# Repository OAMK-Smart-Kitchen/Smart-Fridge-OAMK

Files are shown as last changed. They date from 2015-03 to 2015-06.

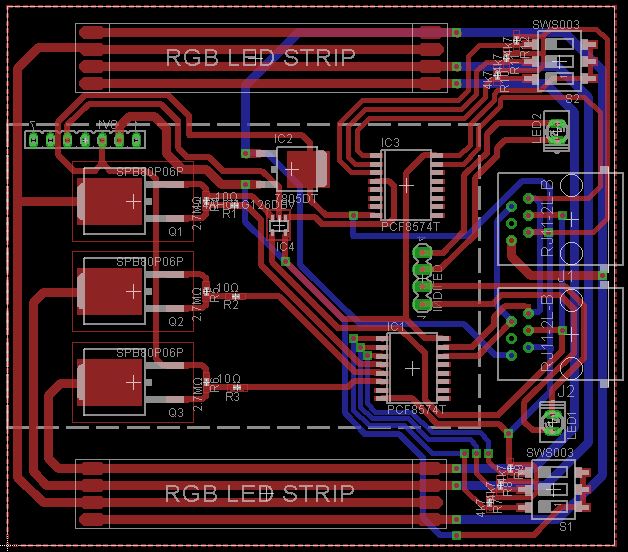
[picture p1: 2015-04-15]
SmartKitchen-Emdebbed System/Hardware/PCB-designs/BRD 2 .JPG

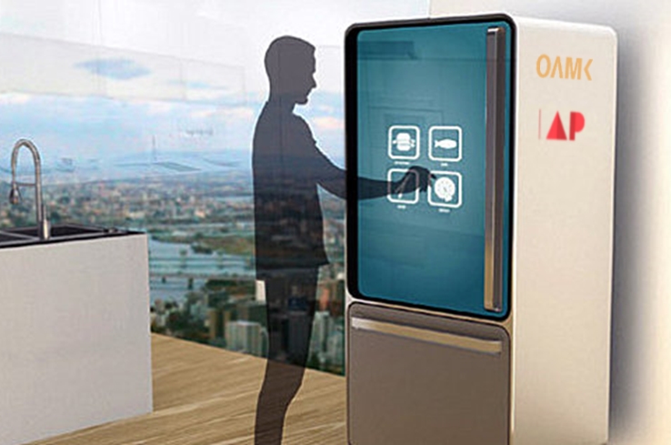
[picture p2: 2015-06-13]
SmartKitchen-Emdebbed System/Documents/Report/Contents/front.jpg

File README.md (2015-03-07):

# Smart-Fridge-OAMK
The first project of the 'Smart Kitchen' commissioned by OAMK University of Applied Sciences in Oulu - Finland.

The concept: [Prezi](http://prezi.com/kkwk0fvxtakd/?utm_campaign=share&utm_medium=copy&rc=ex0share)
The Moqups: [Moqups](https://moqups.com/berndv/YKEUgVQ0)

Dedicated to Tom Mampaey and Bernd Verhofstadt (Erasmus students from Belgium) by:

### Contactpersons Finland:
#### Mr. Jussi Kangasoja
Email: Jussi.Kangasoja@oamk.fi

#### Ms. Kaisa Orajärvi
Email: kaisa.orajarvi@oamk.fi

### Contactperson Belgium:
#### Mr. Jeroen Doggen
Email: jeroen.doggen@ap.be

Github: [github.com/jeroendoggen](https://github.com/jeroendoggen)

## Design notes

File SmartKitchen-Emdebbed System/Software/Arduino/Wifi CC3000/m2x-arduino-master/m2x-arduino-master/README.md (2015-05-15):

Arduino M2X API Client
=====================

The Arduino library is used to send/receive data to/from [AT&amp;T's M2X service](https://m2x.att.com/) from [Arduino](http://www.arduino.cc/) based devices.

**NOTE**: Unless stated otherwise, the following instructions are specific to [Arduino Uno](http://arduino.cc/en/Main/arduinoBoardUno) board. If you are using other boards, the exact steps may vary.

Getting Started
==========================
1. Signup for an [M2X Account](https://m2x.att.com/signup).
2. Obtain your _Master Key_ from the Master Keys tab of your [Account Settings](https://m2x.att.com/account) screen.
3. Create your first [Data Source Blueprint](https://m2x.att.com/blueprints) and copy its _Feed ID_.
4. Review the [M2X API Documentation](https://m2x.att.com/developer/documentation/overview).
5. Obtain an Arduino with built in wifi or ethernet, or a separate wifi or ethernet shield and [set it up](http://arduino.cc/en/Guide/HomePage). These docs were written for an [__Arduino Uno__](http://arduino.cc/en/Main/arduinoBoardUno) with a wifi or ethernet shield but the instructions can be adapted for other Arduino models.

Please consult the [M2X glossary](https://m2x.att.com/developer/documentation/glossary) if you have questions about any M2X specific terms.

How to Install the library
==========================

This library depends on [jsonlite](https://github.com/citrusbyte/jsonlite), the installation steps are as follows:

1. Clone the [jsonlite](https://github.com/citrusbyte/jsonlite) repository.

   **NOTE**: Since we are now using the old v1.1.2 API(we will migrate to the new API soon), please use the fork version of jsonlite listed above instead of the original one.

2. Open the Arduino IDE, click `Sketch->Import Library...->Add Library...`, then navigate to `amalgamated/jsonlite` folder in the cloned jsonlite repository. The jsonlite library will be imported to Arduino this way.

   **NOTE**: If you cloned the jsonlite library, there will be 3 folders named jsonlite:
   * `jsonlite`: the repo folder
   * `jsonlite/jsonlite`: the un-flattened jsonlite source folder
   * `jsonlite/amalgamated/jsonlite`: the flattened jsonlite source for arduino

   The last one here should be the one to use, the first 2 won't work!
3. Use the instructions outlined in Step 2 above to import the `M2XStreamClient` library in the current folder.
4. Now you can find M2X examples under `File->Examples->M2XStreamClient`
5. Enjoy coding!

Hardware Setup
==============

Board Setup
-----------

The Arduino website has a very good [tutorial](http://arduino.cc/en/Guide/HomePage) on setting up the Arduino board. It contains detailed instructions on how to install the Arduino IDE, sets up your board for initial testing. Feel free to proceed to the [Arduino site](http://arduino.cc/en/Guide/HomePage) to get a basic idea on Arduino.

Wifi/Ethernet Shield Setup
--------------------------

If you are using an [Arduino Yun](http://arduino.cc/en/Main/ArduinoBoardYun) board instead of an [Arduino Uno](http://arduino.cc/en/Main/ArduinoBoardUno) board, you can skip this section since the Yun board already has Wifi adapter on board.

To send data to the AT&amp;T M2X service, or receive data from the AT&amp;T M2X service, your Arduino board needs a connection to the Internet. Hence an Arduino [Wifi Shield](http://arduino.cc/en/Main/ArduinoWiFiShield) or [Ethernet Shield](http://arduino.cc/en/Main/ArduinoEthernetShield) is needed to give your board the power to connect to the Internet. To install the shield, hook the shield on your Arduino board — you can use the pins on the shield the same way as the real pins on the Arduino boards.

Sensor Setup
------------

Different sensors can be hooked up to an Arduino board to provide different properties including temperatures, humidity, etc. You can use a breadboard as well as wires to connect different sensors to your Arduino. For detailed tutorial on connecting different sensors, please refer to the Arduino [Examples page](http://arduino.cc/en/Tutorial/HomePage).

3G Shield Setup
------------

If you are using a 3G GSM/GPRS shield with your Arduino, the [M2X Arduino SIMCOM module](https://github.com/attm2x/m2x-arduino-simcom) can be used to connect your device to the AT&T cellular data network.

Variables used in Examples
==========================

In order to run the given examples, different variables need to be configured. We will walk through those variables in this section.

Network Configuration
---------------------

If you are using a Wifi Shield, the following variables need configuration:

```
char ssid[] = "<ssid>";
char pass[] = "<WPA password>";
```

Just fill in the SSID and password of the Wifi hotspot, you should be good to go.

For an Ethernet Shield, the following variables are needed:

```
byte mac[] = { 0xDE, 0xAD, 0xBE, 0xEF, 0xFE, 0xED };
IPAddress ip(192,168,1,17);
```

For a newer Ethernet Shield, the MAC address should be printed on a sticker on the shield. However, some sold Ethernet Shields have no MAC address shown on the board. In this case, you can use any MAC address, as long as it is not conflicted with another network device within the same LAN.

The IP address here is only used when DHCP fails to give a valid IP address. It is recommended, though not required, to provide a unique IP address here.

M2X API Key
-----------

Once you [register](https://m2x.att.com/signup) for an AT&amp;T M2X account, an API key is automatically generated for you. This key is called a _Primary Master Key_ and can be found in the _Master Keys_ tab of your [Account Settings](https://m2x.att.com/account). This key cannot be edited nor deleted, but it can be regenerated. It will give you full access to all APIs.

However, you can also create a _Data Source API Key_ associated with a given Data Source(Feed), you can use the Data Source API key to access the streams belonging to that Data Source.

You can customize this variable in the following line in the examples:

```
char m2xKey[] = "<M2X access key>";
```

Feed ID
-------

A feed is associated with a data source, it is a set of data streams, such as streams of locations, temperatures, etc. The following line is needed to configure the feed used:

```
char feedId[] = "<feed id>";
```

Stream Name
------------

A stream in a feed is a set of timed series data of a specific type(i,e. humidity, temperature), you can use the M2XStreamClient library to send stream values to M2X server, or receive stream values from M2X server. Use the following line to configure the stream if needed:

```
char streamName[] = "<stream name>";
```

Using the M2XStreamClient library
=========================

The M2X Arduino library can be used with both Wifi connection and Ethernet connection. For a Wifi connection, use the following code:

```
WiFiClient client;
M2XStreamClient m2xClient(&client, m2xKey);
```

For an Ethernet connection, use the following code:

```
EthernetClient client;
M2XStreamClient m2xClient(&client, m2xKey);
```

If you are using an [Arduino Yun](http://arduino.cc/en/Main/ArduinoBoardYun) board specifically, you should use the following code:

```
YunClient client;
M2XStreamClient m2xClient(&client, m2xKey);
```

In the M2XStreamClient, 4 types of API functions are provided here:

* `send`: Send stream value to M2X server
* `receive`: Receive stream value from M2X server
* `updateLocation`: Send location value of a feed to M2X server
* `readLocation`: Receive location values of a feed from M2X server

Returned values
---------------

For all those functions, the HTTP status code will be returned if we can fulfill a HTTP request. For example, `200` will be returned upon success, `401` will be returned if we didn't provide a valid M2X API Key.

Otherwise, the following error codes will be used:

```
static const int E_NOCONNECTION = -1;
static const int E_DISCONNECTED = -2;
static const int E_NOTREACHABLE = -3;
static const int E_INVALID = -4;
static const int E_JSON_INVALID = -5;
```

Post stream value
-----------------

The following functions can be used to post value to a stream, which belongs to a feed:

```
template <class T>
int post(const char* feedId, const char* streamName, T value);
```

Here we use C++ templates to generate functions for different types of values, feel free to use values of `float`, `int`, `long` or even `const char*` types here.

Post multiple values
--------------------

M2X also supports posting multiple values to multiple streams in one call, use the following function for this:

```
template <class T>
int postMultiple(const char* feedId, int streamNum,
                 const char* names[], const int counts[],
                 const char* ats[], T values[]);
```

Please refer to the comments in the source code on how to use this function, basically, you need to provide the list of streams you want to post to, and values for each stream.

Fetch stream value
------------------

Since Arduino board contains very limited memory, we cannot put the whole returned string in memory, parse it into JSON representations and read what we want. Instead, we use a callback-based mechanism here. We parse the returned JSON string piece by piece, whenever we got a new stream value point, we will call the following callback functions:

```
void (*stream_value_read_callback)(const char* at,
                                   const char* value,
                                   int index,
                                   void* context);

```

The implementation of the callback function is left for the user to fill in, you can read the value of the point in the `value` argument, and the timestamp of the point in the `at` argument. We even pass the index of this this data point in the whole stream as well as a user-specified context variable to this function, so as you can perform different tasks on this.

To read the stream values, all you need to do is calling this function:

```
int fetchValues(const char* feedId, const char* streamName,
                stream_value_read_callback callback, void* context,
                const char* startTime = NULL, const char* endTime = NULL,
                const char* limit = NULL);
```

Besides the feed ID and stream name, only the callback function and a user context needs to be specified. Optional filtering parameters such as start time, end time and limits per call can also be used here.

Update Datasource Location
--------------------------

You can use the following function to update the location for a data source(feed):

```
template <class T>
int updateLocation(const char* feedId, const char* name,
                   T latitude, T longitude, T elevation);
```

Different from stream values, locations are attached to feeds rather than streams.

The reasons we are providing templated function is due to floating point value precision: on most Arduino boards, `double` is the same as `float`, i.e., 32-bit (4-byte) single precision floating number. That means only 7 digits in the number is reliable. When we are using `double` here to represent latitude/longitude, it means only 5 digits after the floating point is accurate, which means we can represent as accurate to ~1.1132m distance using `double` here. If you want to represent cordinates that are more specific, you need to use strings here.

Read Datasource Location
------------------------

Similar to reading stream values, we also use callback functions here. The only difference is that different parameters are used in the function:

```
void (*location_read_callback)(const char* name,
                               double latitude,
                               double longitude,
                               double elevation,
                               const char* timestamp,
                               int index,
                               void* context);

```

For memory space consideration, now we only provide double-precision when reading locations. An index of the location points is also provided here together with a user-specified context.

The API is also slightly different, in that the stream name is not needed here:

```
int readLocation(const char* feedId, location_read_callback callback,
                 void* context);

```

Delete Values
-------------

You can use the following function to delete values within a stream by providing a `from` and `end` date/time:

```
int deleteValues(const char* feedId, const char* streamName, 
                 const char* from, const char* end);
```

The timestamps `from` and `end` need to be in an ISO 8601 format: yyyy-mm-ddTHH:MM:SS.SSSZ. Note the Z for Zulu time.

Examples
========

We provide a series of examples that will help you get an idea of how to use the `M2XStreamClient` library to perform all kinds of tasks.

Note that the examples may apply to certain types of boards. For example, the ones with `Uno` in the name apply to `Arduino Uno` boards, while the ones with `Yun` apply to `Arduino Yun` boards.

Note that the examples contain fictionary variables, and that they need to be configured as per the instructions above before running on your Arduino board. Each of the examples here also needs either a Wifi Shield or an Ethernet Shield hooked up to your device.

In the `UnoPost`, `EthernetUnoPost` and `YunPost`, a temperature sensor, a breadboard and 5 wires are also needed to get temperature data, you need to wire the board like [this](http://cl.ly/image/3M0P3T1A0G0l) before running the code.

After you have configured your variables and the board, plug the Arduino board into your computer via a Micro-USB cable, click `Verify` in the Arduino IDE, then click `Upload`, and the code should be uploaded to the board. You can check all the outputs in the `Serial Monitor` of the Arduino IDE.

UnoPost
-------

This example shows how to post temperatures to M2X server. Before running this, you need to have a valid M2X Key, a feed ID and a stream name. The Arduino board needs to be configured like [this](http://cl.ly/image/3M0P3T1A0G0l). In this example, we are using an [Arduino Uno](http://arduino.cc/en/Main/arduinoBoardUno) board. If you are using other boards, keep in mind that we are reading from `A0` in the code, the wiring should be similar to this one shown in the illustration.

UnoPostMultiple
---------------

This example shows how to post multiple values to multiple streams in one API call.

UnoFetchValues
--------------

This example reads stream values from M2X server. And prints the stream data point got to Serial interface. You can find the actual values in the Arduino `Serial Monitor`.

EthernetUnoPost
---------------

This one is similar to the `UnoPost`, except that EthernetClient is used instead of WifiClient. If you are using an Ethernet Shield instead of a Wifi Shield, you can use this example.

EthernetUnoReceive
------------------

This one is similar to the `UnoReceive`, except that EthernetClient is used instead of WifiClient.

UnoUpdateLocation
-----------------

This one sends location data to M2X server. Idealy a GPS device should be used here to read the cordinates, but for simplicity, we just use pre-set values here to show how to use the API.

UnoReadLocation
---------------

This one reads location data of a feed from M2X server, and prints them to Serial interfact. You can check the output in the `Serial Monitor` of the Arduino IDE.

UnoDelete
---------

This example shows how to delete values within a stream by providing a date/time range.

YunPost
-------

This example works like `YunPost`, except that it works on an [Arduino Yun](http://arduino.cc/en/Main/ArduinoBoardYun) board instead of an [Arduino Uno](http://arduino.cc/en/Main/arduinoBoardUno) board.

LICENSE
=======

This library is released under the MIT license. See [`M2XStreamClient/LICENSE`](M2XStreamClient/LICENSE) for the terms.

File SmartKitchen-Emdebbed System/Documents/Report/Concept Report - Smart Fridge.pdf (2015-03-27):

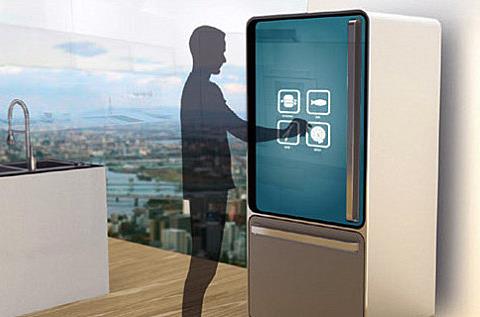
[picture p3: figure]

# Smart Refrigerator

# The first device of the smart kitchen - Seesam

### Tom Mampaey & Bernd Verhofstadt

### Bachelor Electronics – ICT Erasmusstudents: Belgium OAMK - University of Applied Sciences Jan – May 2015

## Table of contents:

## 1. Introduction:

We are both third-year students from ‘Artesis Plantijn Antwerp’ in Belgium. When we saw the opportunity to go on Erasmus to Oulu in Finland and do our Bachelor-project there we did everything to make it possible.
Here we are, and we are very thrilled about the project we got!

## 2. The project:

The project we are doing is a daughter-project of a bigger project of two years to put some intelligence into the ordinary kitchen (Seesam). We have the privilege to be the first two students to contribute to this project.

As stated in the title, we will delve us into the smart refrigerator!
The main idea is to make a refrigerator that will know who’s using it, what he may and what he may not eat and what’s in the refrigerator. The refrigerator will know this based on the current properties of the user (scale for weight, input, BMI-calculator,…).

## 3. Github:

To maintain the structure, workflow and to easily monitor the project we have made a repository on Github for this project. Our request to make it private should be accepted soon. You can find the repository on:
https://github.com/TomMampaey/Smart-Fridge.git

Note: If you have a git-account we can add you to the view-members.

## 4. The idea’s and brainstorm:

- User recognition:
- Fingerprint reader in handheld:
PRO | CONTRA
Very unique (for each person) | You have to touch something
Reliability | Difficult with wet fingers
| Waiting-time
- Active RFID key-hanger or card:
PRO | CONTRA
Detection on distance | Physical object
Multiple use and handy | Can mix up multiple users
Cheap
- Kinect face-recognition:
PRO | CONTRA
Challenging | Delay(?)
Automatic recognition | Height of camera
International team-work | Complex
- Face-recognition Raspberry-Pi:
PRO | CONTRA
Automatic recognition | Delay(?)
Cheap | Height of camera
| Reliability
- Voice-recognition:
PRO | CONTRA
Accessibility | Complex
Cheap | Reliability
Fun
- Motion-detection:
PRO | CONTRA
Energy-saving (only on when motion) | No direct user-recognition
Cheap | Reliability
Easy

- Product recognition and recommendation:
- Barcode-reader:
PRO | CONTRA
Existing databases | Finding a fast way to scan it
| By hand
| Takes time
- NFC-tag:
PRO | CONTRA
Wireless | Attach on the products/tray
Stickers are cheap | Reader on every place
Place-independent
- Mechanical detection/hatches:
PRO | CONTRA
Overview and organization | Moving parts
Reliability | Expensive
Not possible to take other product
- LED’s/ LED-strip
PRO | CONTRA
Clearly what product it is | User can take other products.
Colors for good and bad
Fancy

- Health-detection:
- Integrated scale:
PRO | CONTRA
User-assuredness | Big surface-area
Possibility to calculate BMI | View
No extra action required (for user)
- Personal point-system (based on earlier snacks):
PRO | CONTRA
Motivating for users | Requires many properties of user
Competitive
Possibility to turn off feature
- BMI-calculator:
PRO | CONTRA
Easy calculation | Requires (many) properties of user
User can compare to average | Frustrating
Possibility to turn off feature
- Communication/Platform:
- Raspberry Pi:
PRO | CONTRA
Performance | Limited hardware ports
All-in one computer
Internet-connection
- Arduino:
PRO | CONTRA
Perfect test-device | No internet-connection
Many possibilities | Limited hardware-set
Cheap
- Wi-Fi and Ethernet (LAN):
PRO | CONTRA
Connected devices | Security
Software updates
Monitoring
- Bluetooth:
PRO | CONTRA
Peer-to-peer | Not always reliable
Not connected to the internet | Possible delays
| Can only connect 2 devices at once

Subject | Week 1 | Week 2 | Week 3 | Week 4 | Week 5 | Week 6 | Week 7 | Week 8 | Week 9 | Week 10
Documentation:
Concept-report
Gantt-chart/Project-planning
Brainstroming
Comparing possibilities
Hardware:
Research (target)
Experimenting
Features
Collectting components
Powersupply
Communication
Arduino
Raspberry Pi
User-recognition
Testing
Schematic-design
PCB-desgin
PCB-manufacture
Prototyping
Error analyzes
Software:
Research
Choosing Language(s)
User-recognition
Raspberry Pi
Features
Server-side
GUI
Final:
Final integrating Software - Hardware Finishing hardware
Final Report
Finnishing touth Final Report

## 5. Estimated Gantt-chart:

Subject | Week 11 | Week 12 | Week 13 | Week 14 | Week 15 | Week 16 | Week 17 | Week 18 | Week 19 | Week 20
Documentation:
Brainstroming
Concept-report
Gantt-chart/Project-planning Comparing possibilities
Hardware:
Research (target)
Experimenting
Features
Collectting components
Powersupply
Communication
Arduino
Raspberry Pi
User-recognition
Testing
Schematic-design
PCB-desgin
PCB-manufacture
Prototyping
Error analyzes
Software:
Research
Choosing Language(s)
User-recognition
Raspberry Pi
Features
Server-side
GUI
Final:
Final integrating Software - Hardware Finishing toutch hardware
Final Report
Finnishing Final Report

## The Annex:

Content:

Will be added soon.

Images:

- Front-page image:
http://www.revistaexclusiva.com/?p=25851

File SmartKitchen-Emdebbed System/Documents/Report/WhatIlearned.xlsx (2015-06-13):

Subject | Beginner | Experienced | Advanced | Expert
SMD - design multiple layers
Component desing
Prototyping
SMD component techniques
Arduino/coding
Reasearch/Datasheets
Github
PCB design and placements
Sensors
Schematics
Microscope comp. Placing
Shield construction
Measurement/test equipment
Hardware/Software debug!
I2C protocol
Near Field Communication
WiFi, HTTP methods, ...
PCB manufacturing
Handeling unexpected failures
ASUS Xtion PRO
Raspberry Pi
3D-printing
M2X Development
iPi Mocap Studio
RF-ID
Microsoft Kinect
Wheatstone bridge weightscale
Working independently
Planning skills
Cooperate in English
Tutorial
Time management
Teamwork
Scrum
Preparing meetings
Note: geldt enkel voor dit project, en enkel wat ik heb bijgeleerd!!

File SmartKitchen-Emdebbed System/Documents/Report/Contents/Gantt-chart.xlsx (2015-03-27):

Subject | Week 1 | Week 2 | Week 3 | Week 4 | Week 5 | Week 6 | Week 7 | Week 8 | Week 9 | Week 10 | Subject | Week 11 | Week 12 | Week 13 | Week 14 | Week 15 | Week 16 | Week 17 | Week 18 | Week 19 | Week 20
Documentation: |  |  |  |  |  |  |  |  |  |  | Documentation:
Concept-report |  |  |  |  |  |  |  |  |  |  | Brainstroming
Gantt-chart/Project-planning |  |  |  |  |  |  |  |  |  |  | Concept-report
Brainstroming |  |  |  |  |  |  |  |  |  |  | Gantt-chart/Project-planning
Comparing possibilities |  |  |  |  |  |  |  |  |  |  | Comparing possibilities
Hardware: |  |  |  |  |  |  |  |  |  |  | Hardware:
Research (target) |  |  |  |  |  |  |  |  |  |  | Research (target)
Experimenting |  |  |  |  |  |  |  |  |  |  | Experimenting
Features |  |  |  |  |  |  |  |  |  |  | Features
Collectting components |  |  |  |  |  |  |  |  |  |  | Collectting components
Powersupply |  |  |  |  |  |  |  |  |  |  | Powersupply
Communication |  |  |  |  |  |  |  |  |  |  | Communication
Arduino |  |  |  |  |  |  |  |  |  |  | Arduino
Raspberry Pi |  |  |  |  |  |  |  |  |  |  | Raspberry Pi
User-recognition |  |  |  |  |  |  |  |  |  |  | User-recognition
Testing |  |  |  |  |  |  |  |  |  |  | Testing
Schematic-design |  |  |  |  |  |  |  |  |  |  | Schematic-design
PCB-desgin |  |  |  |  |  |  |  |  |  |  | PCB-desgin
PCB-manufacture |  |  |  |  |  |  |  |  |  |  | PCB-manufacture
Prototyping |  |  |  |  |  |  |  |  |  |  | Prototyping
Error analyzes |  |  |  |  |  |  |  |  |  |  | Error analyzes
Software: |  |  |  |  |  |  |  |  |  |  | Software:
Research |  |  |  |  |  |  |  |  |  |  | Research
Choosing Language(s) |  |  |  |  |  |  |  |  |  |  | Choosing Language(s)
User-recognition |  |  |  |  |  |  |  |  |  |  | User-recognition
Raspberry Pi |  |  |  |  |  |  |  |  |  |  | Raspberry Pi
Features |  |  |  |  |  |  |  |  |  |  | Features
Server-side |  |  |  |  |  |  |  |  |  |  | Server-side
GUI |  |  |  |  |  |  |  |  |  |  | GUI
Final: |  |  |  |  |  |  |  |  |  |  | Final:
Final integrating Software - Hardware |  |  |  |  |  |  |  |  |  |  | Final integrating Software - Hardware
Finishing hardware |  |  |  |  |  |  |  |  |  |  | Finishing toutch hardware
Final Report |  |  |  |  |  |  |  |  |  |  | Final Report
Finnishing touth Final Report |  |  |  |  |  |  |  |  |  |  | Finnishing Final Report

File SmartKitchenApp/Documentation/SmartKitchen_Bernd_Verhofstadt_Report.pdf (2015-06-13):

# Project

# Sesam

-‐

# Smart

# Kitchen Smart

# Fridge

Spring

2015

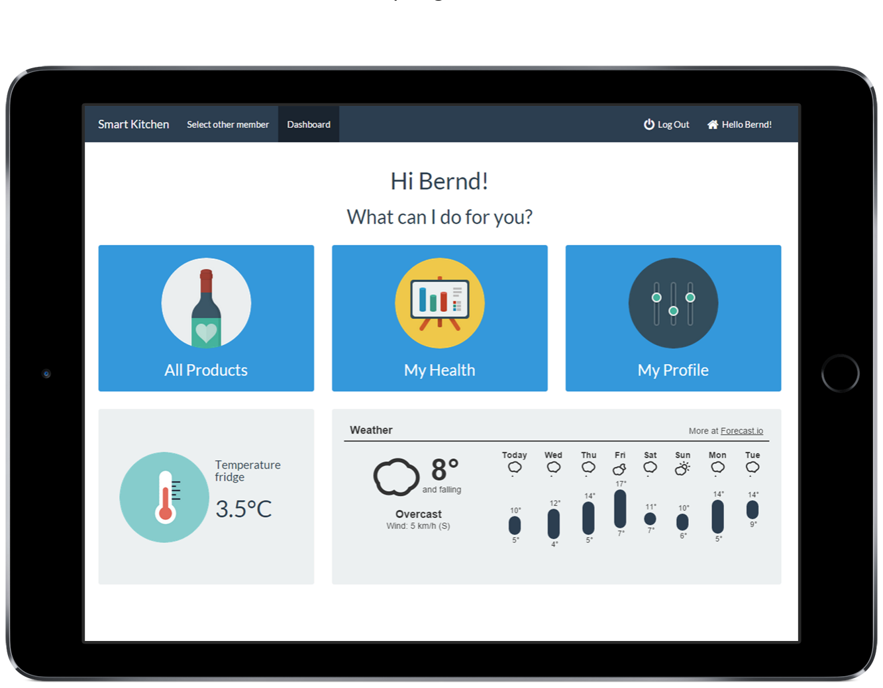
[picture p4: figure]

Student
Bernd

Verhofstadt
Heiligenweg

29
D-‐47626

Kevelaer
bernd.verhofstadt@outlook.com

Sending

institution
Artesis

Plan8jn

University

College
Paardenmarkt

92
2180

Antwerp
Belgium

Receiving

institution
OAMK

-‐

Oulun

seudun

ammaAkorkeakoulu
Kotkantie

1
90250

Oulu
Finland

© 2015 Bernd Verhofstadt | Smart Fridge | Page 2 of 16

## Table

of

## contents

1. Introduction

4
2. Brainstorm

5
3. Research

5
4. Work

Methods

6
User

requirements

6
Scrum

board

6
Weekly

meeting

7
Standup

meeting

7
Sprint

8
Git

8
5. SoVware

structure

8
Front

end

8
Back

end

8
6. Application

9
Frameworks

and

technologies

10
User

interface

10
GitHub

13
Windows

Application

13
7. Web

Api

2

14
Frameworks

and

technologies

15
GitHub

15
Technical

information

with

problems

and

solutions

15
8. Reference

list

16

## 1. Introduction

Technology

is

not

standing

still.

We

want

more

and

more

automated

devices.

These

devices

will

be

used
on

a

daily

basis.

A

house

is

a

place

where

you

can

find

a

lot

of

these

things,

for

example

the

kitchen.

The
Sesam

project

is

based

on

a

voice

character.

When

you

call

Sesam,

he/she

can

do

something

like

“Sesam
open”.

The

Sesam

project

is

a

smart

kitchen

where

you

could

do

the

same.

For

this

project

I

worked

with
Tom

Mampaey

on

the

Smart

Fridge,

a

spin-‐off

from

the

Smart

Kitchen.

In

the

beginning

we

had

only

two
words.

Smart

and

Kitchen.

## 2. Brainstorm

The

first

step

to

the

project

was

our

brainstorming

session.

A

blank

paper

on

the

table

with

only

the
words

‘Smart

Fridge’.

The

ideas

that

where

wriben

on

the

paper

where

very

different.

Some

major

ideas:
-‐

When

standing

before

the

fridge,

you’ll

be
recognized
-‐

Voice

control

like

Siri,

Google

now,

…

-‐>
Text-‐To-‐Speech

and

Speech-‐To-‐Text
-‐

Glass

screen

with

touch

functionality
-‐

See

what

products

are

in

the

fridge
-‐

Get

recipes

suggestions

what’s

in

the
fridge
-‐

Challenge

your

family

with

points

to

eat

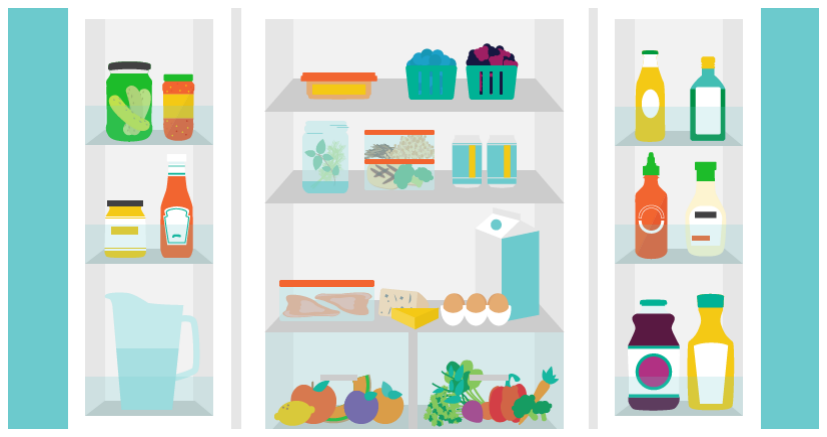
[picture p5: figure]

healthy
-‐

Order

food

online

on

your

fridge
With

these

ideas

we

made

a

selection,

what

looked

possible

in

a

Gme

period

of

four

months.

To

discover
the

possibilities

we

did

some

research

and

tests.

## 3. Research

The

first

thing

that

I

wanted

to

make,

was

a

user

interface.

Easiest

thing

that

I

could

do

was

grab

a
computer,

screen,

keyboard

and

mouse

and

build

it

in

the

fridge.

This

solution

is

not

the

best

one…

It’s
expensive

and

overkill

on

hardware.

So

we

decided

that

we

wouldn’t

use

a

desktop

computer

in

the
fridge.
As

mentioned

above,

a

full

size

computer

isn’t

the

best

option.

But

when

there

are

computers

with
limited

hardware

which

are

less

expensive,

like

Raspberry

Pi

it

could

be

a

great

choice.
I

started

with

doing

tests

on

the

Raspberry

Pi.

Voice

control

was

on

the

list

so

I

did

a

lot

of

research

on
this

subject.

I

found

some

companies

that

offered

‘free’

STT

(Speech

to

Text).

I

looked

into

it

but

the
results

were

not

satisfactory.

Google

chrome

was

a

solution

but

as

it

won’t

work

on

Raspberry

pi,

this
wasn’t

an

option.

Because

of

the

limited

budget

and

Gme

that

we

had

to

spend,

I

decided

not

to

use

STT.
I

was

testing

with

Raspberry

Pi

to

make

a

user

interface

but

it

was

not

user

friendly,

you

only

can

use
limited

graphics

due

to

the

limited

hardware.
I

needed

another

solution,

something

more

flexible

to

run.

Everyone

is

using

a

smartphone

or

tablet
these

days,

thus

I

was

thinking

about

a

mobile

application.

But

the

question

was

for

which

OS.

Because
we

didn’t

have

enough

Gme,

we

had

to

make

a

discussion.

I

was

thinking

about

a

responsive

web
application,

in

this

way

you

can

use

it

on

any

device

with

a

modern

browser

and

internet

connection.
The

web

application

should

be

compatible

with

different

devices

and

easy

to

use.

We

decided

that

I
would

make

a

web

app,

which

at

the

end

can

be

converted

to

a

mobile

application

without

a

lot

of
coding.
To

run

a

web

application,

there

are

two

things

that

you

need.

A

web

server

and

data

storage.
The

advantage

of

an

offline

web

application

is

that

you

don’t

need

an

internet

connection.

The

downside
is

that

It’s

more

difficult

to

deploy

and

you

should

make

an

offline

data

storage.

To

make

it

more

dynamical

and

have

more

options,

I

decided

to

make

everything

in

the

cloud.

Luckily

a

web

server
wasn’t

a

problem,

since

I

have

my

personal

one.
For

the

data

storage,

I

had

to

choice

the

most

suitable

technology

for

the

back-‐end.
Next

step

was

to

do

some

tests

with

different

technologies.

In

the

first

place,

I

wanted

to

learn

something

new.

I

wanted

to

use

NodeJS

with

MongoDB.

With

this
technology

I

had

no

experience

or

idea

how

it

works.

I

did

some

small

projects

but

it

seemed

difficult

to
debug

etc.
I

read

an

article

about

MVC

and

Web

API

and

they

said

that

Web

API

2

is

the

future,

but

MVC

will
disappear

in

a

few

years.

So

I

choose

the

best

one,

Web

API

2.

For

the

database,

I

took

MicrosoV

SQL
Server

2014.

To

make

it

more

flexible,

I

will

use

the

MicrosoV

Entity

Framework.

## 4. Work

## Methods

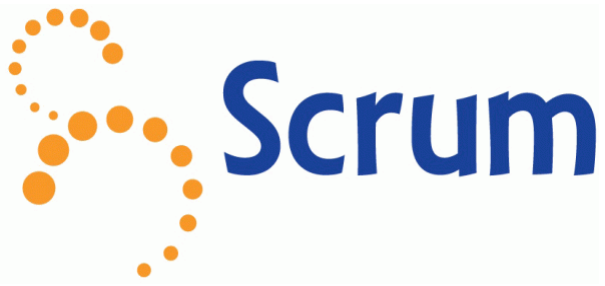
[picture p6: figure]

To

realize

this

project,

we

used

a

few

methods.

The

most
important

one

was

SCRUM.
Scrum

is

a

work

method

that

is

used

for

project
management.

When

using

scrum

there

are

a

lot

of
possibilities,

we

did

a

selection

of

the

most

important
features.

## User

## requirements

I

made

some

user

requirements

for

the

soVware

part.

What

does

the

end

customer

want

?

For

example:
‘As

a

family

member

I

want

to

see

which

products

are

in

the

fridge.

Off

course

we

added

some

priority

to
see

what

we

had

to

do

first.

## Scrum

## board

We

had

a

whiteboard

where

we

made

a

table

with

following

columns:

to

do,

in

progress

and

done.

Framework | Database
.NET MVC | MySQL
Web API 2 | MS SQL
NodeJS | MongoDB

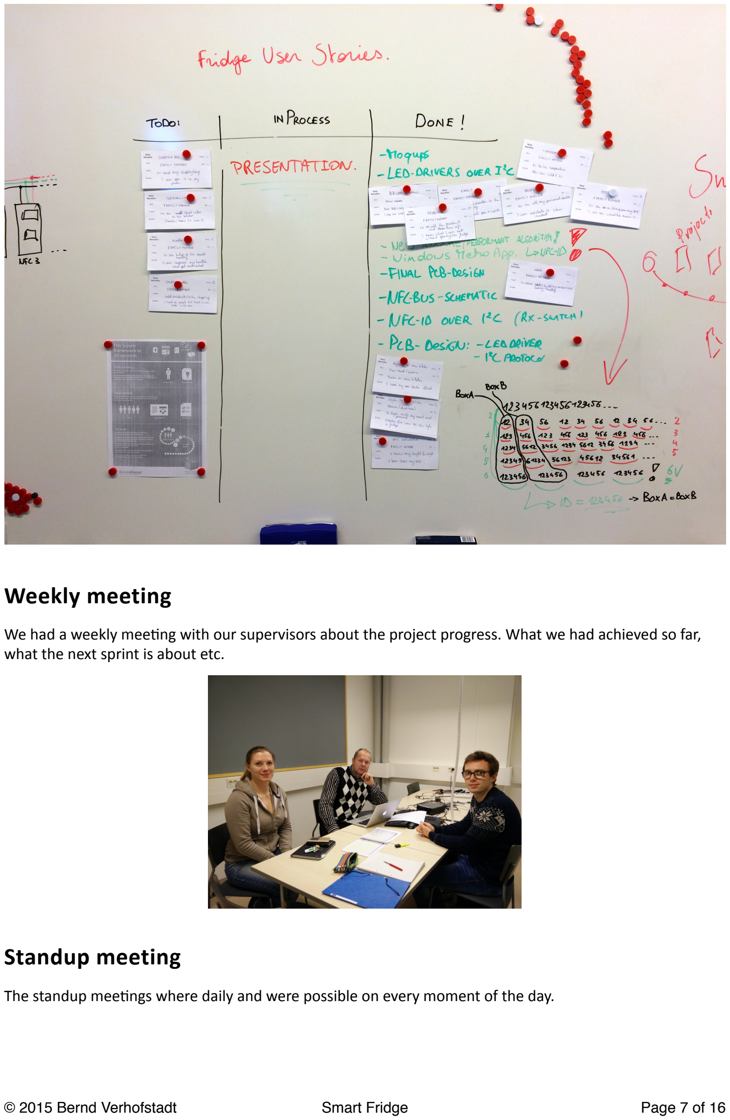
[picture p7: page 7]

## Weekly

## meeting

We

had

a

weekly

meeting

with

our

supervisors

about

the

project

progress.

What

we

had

achieved

so

far,
what

the

next

sprint

is

about

etc.

## Standup

## meeting

The

standup

meetings

where

daily

and

were

possible

on

every

moment

of

the

day.

## Sprint

The

sprint

was

every

two

weeks.

Where

we

had

some

deadlines

that

we

have

to

finish

by

then.

We
discussed

the

sprint

with

the

supervisors.

## Git

We

worked

with

GitHub.

It

is

a

web-‐based

Git

repository

hosting

service,

which

offers

the

full

distributed
revision

control

and

source

code

management

(SCM)

functionality

of

Git

as

well

as

adding

its

own

features.
I

created

an

organization

named

‘OAMK

Smart

Kitchen’

on

GitHub.

All

the

people

that

will

work

on

this
project

can

work

on

there

own

repository

within

the

Smart

Kitchen

organization.
hbps://github.com/OAMK-‐Smart-‐Kitchen (https://github.com/OAMK-Smart-Kitchen)

## 5. Software

## structure

The

soVware

can

be

divided

in

two

parts.

The

back-‐end

and

the

front-‐end.

## Front

## end

The

front

end

is

the

layer

between

the

user

interface

and

the

back

end.

In

the

front

end,

the

client
application

that

is

running,

uses

Angular

/

javascript

to

communicate

with

the

back

end.

The

tablet

is
connected

over

the

home

WiFi

router

with

the

browser

to

the

internet.

## Back

## end

The

back

end

is

the

place

where

the

data

is

stored

on

the

server,

the

point

where

the

user

can

interact

or
request

data

from

the

server.

The

back

end

is

placed

in

a

datacenter.

There

are

several

server

types,

the
Web

server

will

store

the

client

application.

When

the

user

enters

the

URL

from

the

application,

the

web
server

will

send

the

relevant

data

back

to

the

client.
Windows

Server

contains

different

parts,

Sql

Database,

Webtterver

that

runs

Web

API

2

application.

It’s
possible

to

deploy

with

MicrosoV

Deployment

in

Visual

Studio.

The

windows

server

has

a

layer

between

the
Web

API

2

application

and

the

Sql

2014

database,

Entity

Framework.

This

framework

can

generate

a
database

from

a

model,

controller

or

reverse.

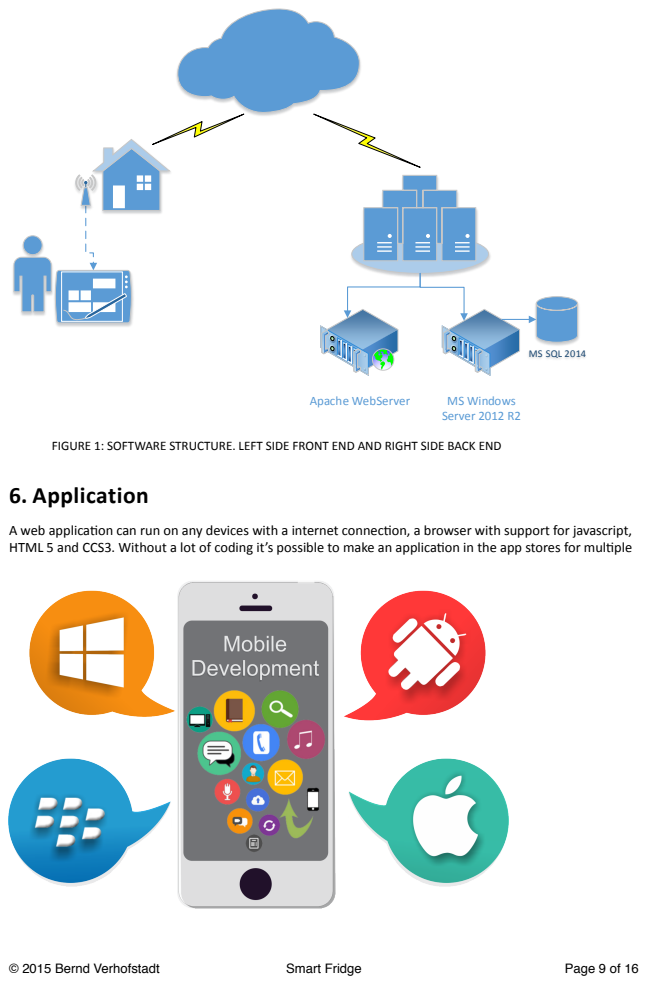
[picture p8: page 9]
FIGURE; SOFTWARE; STRUCTURE.; LEFT; SIDE; FRONT; END; AND; RIGHT; BACK; 6. Application; web; applicaGon; can; run; any; devices; with; internet; connecGon,; browser; support; for; javascript,; HTML; and; CCS3.; Without; lot; coding; possible; make; the; app; stores; mulGple; Apache; WebServer; Windows Server; SQL

OS

with

a

WebView/browser

embedded.

The

web

app

coding

is

for

every

app

the

same,

you

just

have

to
embed

it

in

the

code

of

the

OS.
I

created

a

Windows

App

for

Windows

8

or

higher.

The

Windows

application

contains

a

browser

that

will
load

the

application.

The

advantages

of

a

native

application

is

that

you

have

a

nice

icon

and

don’t

need

any
bookmarks

etc.

The

native

app

will

show

the

web

application

in

full

screen,

in

this

way

the

end

user

will
recognize

it

as

a

real

Mobile

application

and

not

as

an

Website.

## Frameworks

## and

## technologies

- AngularJS
AngularJS

lets

you

write

client-‐side

web

applications

as

if

you

had

a

smarter

browser.

It

lets

you

use

good
old

HTML

as

your

template

language

and

lets

you

extend

HTML’s

syntax

to

express

your

application’s
components

clearly

and

instantly.

It

automatically

synchronizes

data

from

your

UI

(view)

with

your
Javattcript

objects

(model)

through

2-‐way

data

binding.

To

help

you

structure

your

application

beber

and
make

it

easy

to

test,

AngularJS

teaches

the

browser

how

to

do

dependency

injection

and

inversion

of
control.
Oh

yeah

and

it

helps

with

server-‐side

communication,

taming

async

callbacks

with

promises

and
deferreds.

It

also

makes

client-‐side

navigation

and

deep

linking

with

hash-‐bang

URL's

or

HTML5
pushtttate

a

piece

of

cake.

The

best

of

all:

it

makes

development

fun!
- Html
5
HTML

5

is

the

latest

stable

version

of

the

standard.

It

has

a

support

for

geolocation,

we

use

this

for

the
Weather

by

Forecast.io.
- Bootstrap
Bootstrap

is

a

sleek,

intuitive,

and

powerful

front-‐end

framework

for

faster

and

easier

web

development,
created

by

Mark

Obo

and

Jacob

Thornton,

and

maintained

by

the

core

team

with

the

massive

support
and

involvement

of

the

community.

Bootstrap

is

the

most

popular

HTML,

CSS,

and

JS

framework

for
developing

responsive,

mobile

first

projects

on

the

web.

## User

## interface

For

the

user

interface,

I

started

with

a

drawing.

The

drawing

was

a

sketch

with

the

most

important

elements
and

their

shape.

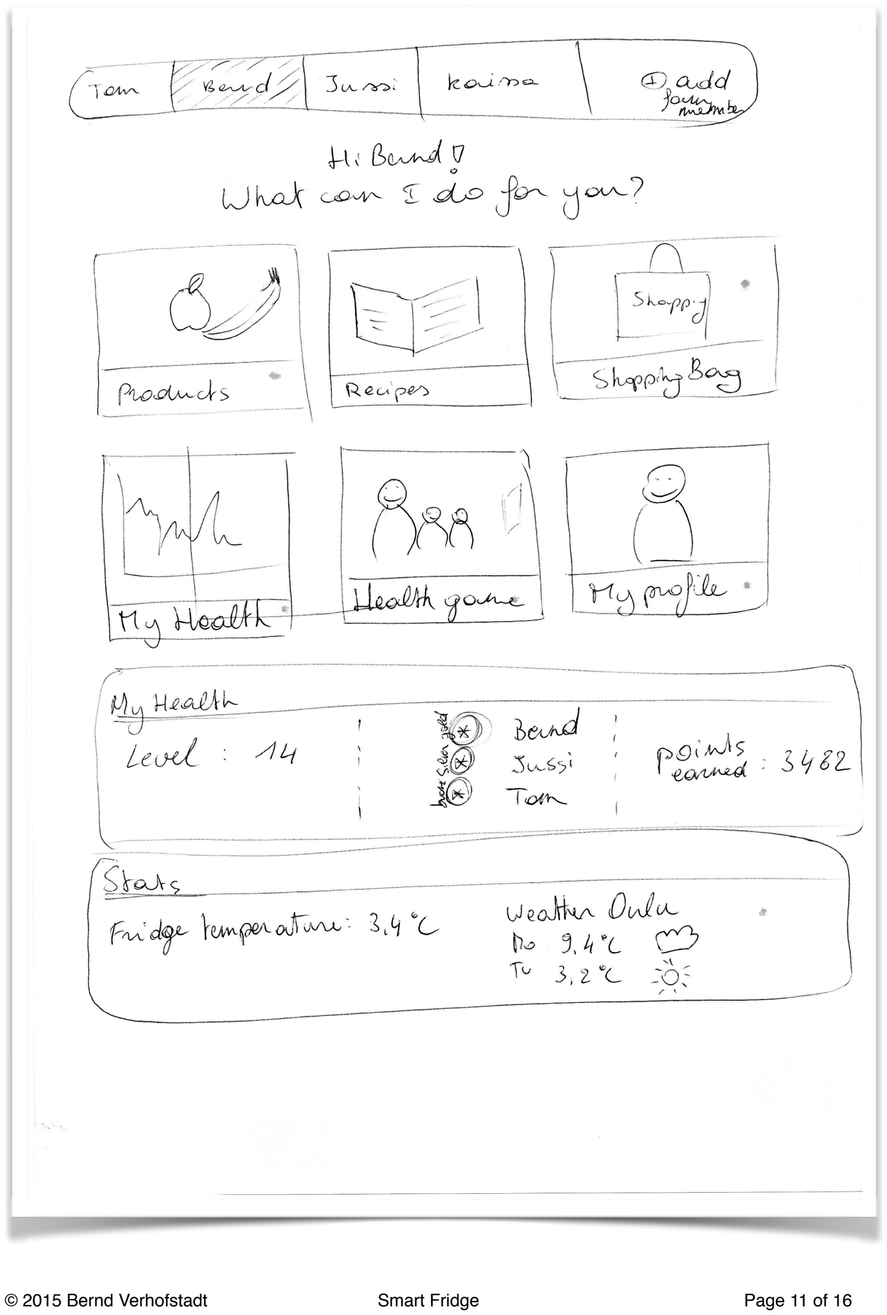
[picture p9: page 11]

When

the

sketches

were

finished,

I

made

them

digital

on

hbp://moqups.com

and

they

looked

like

this:

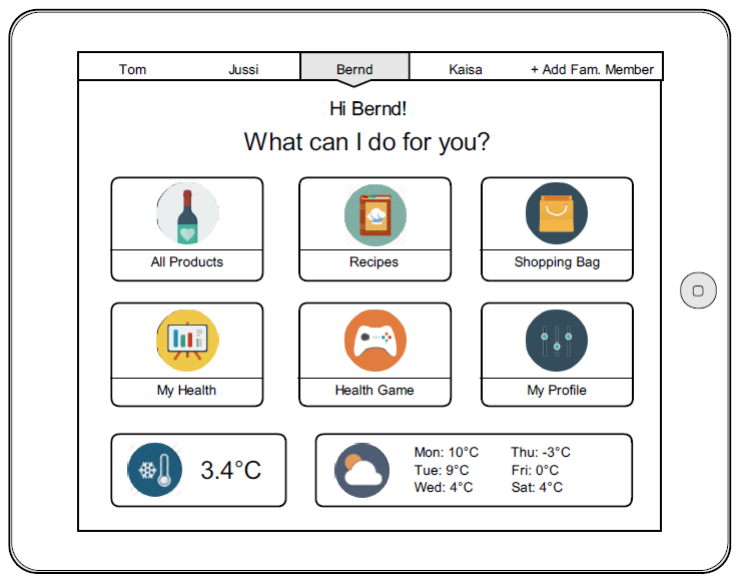
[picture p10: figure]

This

design

is

more

similar

to

the

end

design

in

Bootstrap

(HTML

and

CSS).

Now

it’s

Gme

to

make

it

in

real
code.

The

result

won’t

look

the

same

but

the

major

parts

will

be

similar

to

the

previous

drawings.

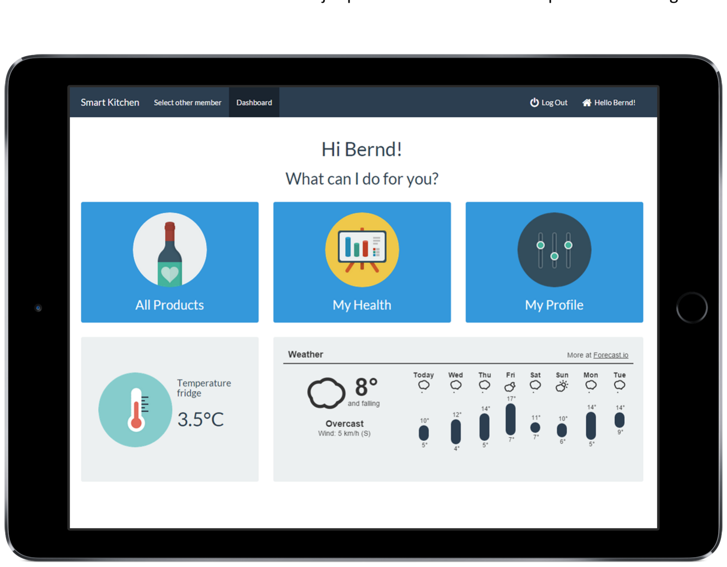
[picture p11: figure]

The

final

design

is

also

responsive

to

multiple

screen

resolution,

from

a

smartphone

in

landscape

to

a

very
large

Screen

size.

## GitHub

The

Web

Application

can

be

found

on

GitHub.
hbps://github.com/OAMK-‐Smart-‐Kitchen/Smart-‐Fridge-‐OAMK (https://github.com/OAMK-Smart-Kitchen/Smart-Fridge-OAMK) People

can

see

and

work

on

the

code,

add

features,

fix

problems

etc.

## Windows

## Application

I

published

this

project

as

a

Windows

8

and

8.1

application

to

the

Windows

Store.

You

can

find

it

on

hbp://
bit.ly/Smart-‐Fridge (http://bit.ly/Smart-Fridge)

## 7. Web

## Api

2

I

did

a

lot

of

research

about

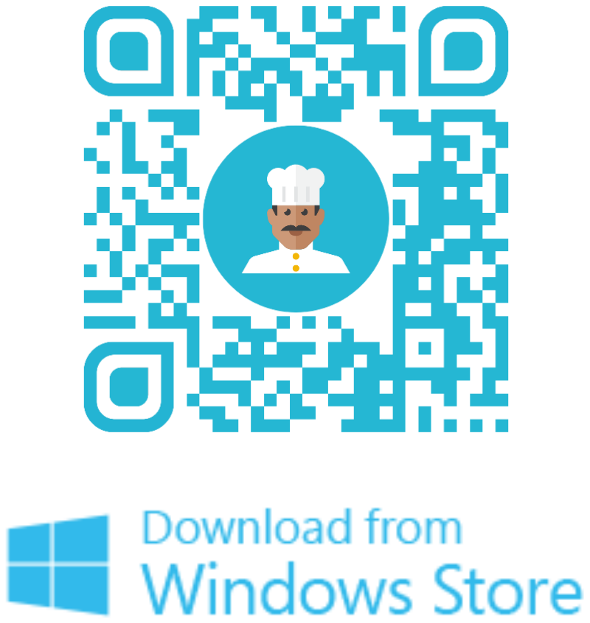
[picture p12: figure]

different

back-‐ends,

I

decided

to

use

Web

API

2.

This

standard

has

a

very

good
community

playorm.

MicrosoV

has

some

examples

and

templates

in

Visual

Studio.

The

Web

API

2

is

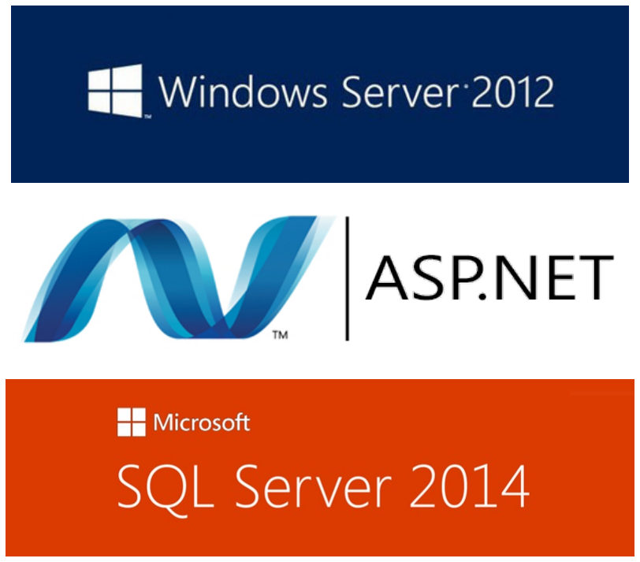
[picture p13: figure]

running

on

a

IIS

8.5

on

a

Windows

Cloud

Server

2012.
Data

storage

is

on

a

Sql

Server

2014

that

runs

on

the

same

Windows

Cloud

Server

2012.

When

the

Web

API
wants

to

get

or

store

data

to

the

Database,

the

Web

API

wants

to

do

that

with

a

SQL

Query.

It

would

have
taken

a

lot

of

Gme

to

write

all

the

queries.

To

save

me

some

Gme,

I

used

a

layer

between

the

Sql

Server

and
the

Web

API

controller,

the

Entity

framework

by

MicrosoV.

## Frameworks

## and

## technologies

- Windows
Server

2012

R2
Windows

Server

is

a

stable

server

OS

thats

great

to

run

applications

of

any

scale.

It's

well

supported

by
MicrosoV.

The

only

minor

point

is

that

you

need

a

License

to

run

this

OS.

Windows

Server

is

known

for
the

feature

packages

that

can

be

installed,

IIS

web

Server,

Directory

Server,

Remote

Desktop,…

When
you

have

some

problems,

you

find

a

solution

faster

due

to

the

verbose

logs.
- Web
API

2
ASP.NET

Web

API

2

is

a

framework

that

makes

it

easy

to

build

HTTP

services

that

reach

a

broad

range

of
clients,

including

browsers

and

mobile

devices.

ASP.NET

Web

API

is

an

ideal

playorm

for

building

RESTful
applications

on

the

.NET

Framework.
- IIS
8.5
IIS

(Internet

Information

Server)

is

a

group

of

Internet

servers

(including

a

Web

or

Hypertext

Transfer
Protocol

server

and

a

File

Transfer

Protocol

server)
- Entity
Framework
Entity

Framework

(EF)

is

an

object-‐relational

mapper

that

enables

.NET

developers

to

work

with
relational

data

using

domain-‐specific

objects.

It

eliminates

the

need

for

most

of

the

data-‐access

code

that
developers

usually

need

to

write.

I

used

the

Model-‐First

method

where

I

designed

a

Model

and
converted

it

to

a

Database

(T-‐SQL).
- SQL
Server

2014
SQL

Server

is

a

relational

database

management

system

(RDBMS)

from

MicrosoV

that's

designed

for

the
enterprise

environment.

SQL

Server

runs

on

T-‐SQL

(Transact

-‐SQL),

a

set

of

programming

extensions

from
Sybase

and

MicrosoV

that

add

several

features

to

standard

SQL,

including

transaction

control,

exception
and

error

handling,

row

processing,

and

declared

variables.

## GitHub

The

Back

end

Application

can

be

found

on

GitHub.
hbps://github.com/OAMK-‐Smart-‐Kitchen/Kitchen-‐Webttervice-‐OAMK (https://github.com/OAMK-Smart-Kitchen/Kitchen-Webttervice-OAMK) People

can

work

on

the

code,

add

features,

fix

problems

etc.

## Technical

## information

## with

## problems

## and

## solutions

I

created

a

wiki

page

on

Github

with

the

most

important

problems

and

the

solution

to

those,

for

example
how

to

Configure

a

Web

API

server

with

the

MicrosoV

SQL

Server.
hbps://github.com/OAMK-‐Smart-‐Kitchen/Kitchen-‐Webttervice-‐OAMK/wiki (https://github.com/OAMK-Smart-Kitchen/Kitchen-Webttervice-OAMK/wiki)

## 8. Reference

## list

2015

Google

-‐

hbps://github.com/angular/angular.js 2015

Google

-‐

hbps://docs.angularjs.org/guide/introduction 2015

Margaret

Rouse

-‐

hbp://searchsqlserver.techtarget.com/definition/SQL-‐Server 2015

Margaret

Rouse

-‐

hbp://searchwindowsserver.techtarget.com/definition/IIS 2015

MicrosoV

-‐

hbp://www.asp.net/entity-‐framework (http://www.asp.net/entity-framework) 2015

MicrosoV

-‐

hbps://msdn.microsoV.com/en-‐us/library/dn448365(v=vs.118).aspx (https://msdn.microsoft.com/en-us/library/dn448365(v=vs.118).aspx) 2015

MicrosoV

-‐

hbps://www.microsoV.com/en-‐us/server-‐cloud/products/windows-‐server-‐2012-‐r2/ (https://www.microsoft.com/en-us/server-cloud/products/windows-server-2012-r2/) 2015

Twiber

-‐

hbps://github.com/twbs/bootstrap

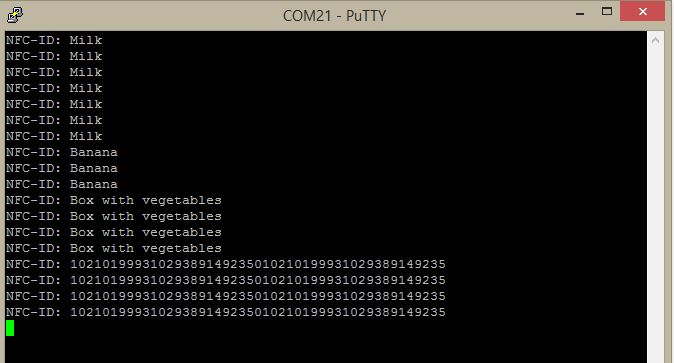
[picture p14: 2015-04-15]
SmartKitchen-Emdebbed System/Hardware/PCB-designs/Capture.JPG

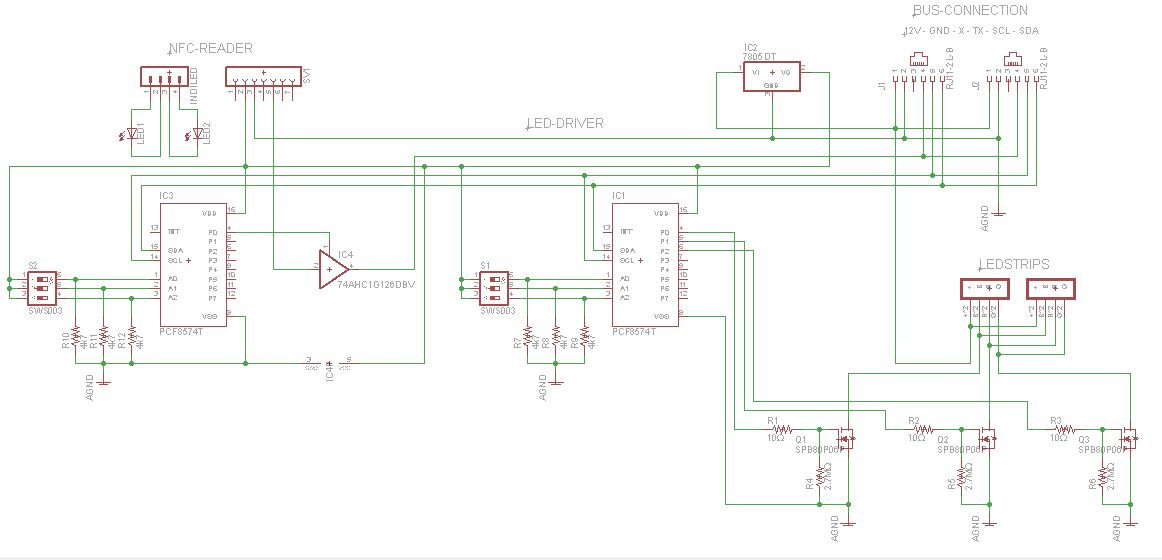
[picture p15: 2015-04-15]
SmartKitchen-Emdebbed System/Hardware/PCB-designs/Schematic 2.JPG

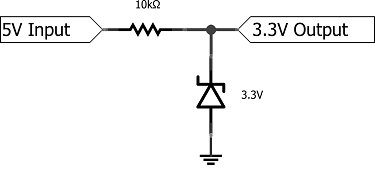
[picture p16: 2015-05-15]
SmartKitchen-Emdebbed System/Documents/Report/Contents/5 tot 3.3.png

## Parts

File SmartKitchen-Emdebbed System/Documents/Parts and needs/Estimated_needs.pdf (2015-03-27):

ID: | Subject/Component: | Use/Part: | Shop/Example/Info: | ≈Price pp:
| Hardware:
1 | Windows Kinect/Asus Pro xtion | User-recognition | http://www.microsoftstore.com/store/mseea/nl_NL/pdp/Kinect-for-Windows-v2-sensor/productID.299242600 OAMK
2 | Kinect Adapter for Windows | User-recognition | http://www.microsoftstore.com/store/msusa/en_US/pdp/Kinect-Adapter-for-Windows/productID.308803600 OAMK
3 | PC | Mastering project (central) | OAMK ? (necessary to connect kinect) | /
4 | Screen or Tablet | GUI on fridge | OAMK ? (Web-application) | /
5 | Arduino Uno | Controlling fridge | OAMK? (got it) | OAMK
6 | Two or more RGB-ledstrips | To indicate needed foods | http://www.dx.com/p/12v-54-led-rgb-light-strip-50cm-11304#.VNd5I_mG8nM € | 20,00
7 | Compennts custom-Arduino-shield | RGB driver,TIP31, expierence,... | https://www.dfrobot.com/index.php?route=product/product&product_id=1032 /
8 | HC-SR04 | To detect distance user | http://www.dx.com/nl/p/hc-sr04-ultrasonic-sensor-distance-measuring-module-133696 € | 3,00
9 | Temprature-sensor | checking (mabe controlling) | http://www.dx.com/p/arduino-digital-temperature-humidity-sensor-module-121350#.VNd6mPmG8nM € | 5,00
10 | (Wifi)Router | Connecting everything | OAMK? | /
11 | Speakers | To interact with user | OAMK? | /
12 | Multiple NFC-readers | To read ingredients (maybe send) | http://www.dx.com/p/13-56mhz-nfc-rfid-shield-module-pn532-for-arduino-iso14443-blue-233152#.VNd-efmG8nM € | 80,00
13 | NFC-stickers | To identify ingredients | http://www.dx.com/p/000142-nfc-tag-smart-electronic-high-frequency-tag-silver-298982#.VNd9svmG8nM € | 15,00
14 | Motion detector | To save energy | http://www.dx.com/p/ir-infrared-motion-detection-sensor-module-dc-5v-20v-139624#.VNd-pfmG8nM € | 2,50
15 | Weight-scale (Foil? Bluetooth? Price?) | Weighing user | http://www.open-electronics.org/wi-fi-body-scale-with-arduino/ | /
| Software:
16 | Database | online data storage (MySQL, ub.) | http://azure.microsoft.com/en-us/ OAMK? | OAMK
17

### Estimated needs:

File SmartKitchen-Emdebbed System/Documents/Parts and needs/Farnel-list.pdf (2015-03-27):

ID: | Subject/Component: | Use/Part: | Quantity | Shop/Example/Info: | ≈Price pp:
| Hardware:
1 | IC, I2C BUS EXPANDER 16DIP | To test on breadboads | 3 | http://be.farnell.com/texas-instruments/pcf8574an/ic-i2c-bus-expander-16dip/dp/1703443 € | 1,17
2 | I/O EXPANDER, 8BIT, I2C, TSSOP-20 | For Final (SMD)-purposes | 6 | http://be.farnell.com/texas-instruments/pcf8574apw/i-o-expander-8bit-i2c-tssop-20/dp/2335654 € | 1,24
3 | LM335AZ/NOPB IC, TEMP SENSOR, 5V, 3-TO-92 | To measure temp in & outside | 3 | http://be.farnell.com/texas-instruments/lm335az-nopb/ic-temp-sensor-5v-3-to-92/dp/1469227 € | 1,20
4 | IC, TEMP SENSOR, 5V, SMD | For Final (SMD)-purposes | 2 | http://be.farnell.com/texas-instruments/lm335m-nopb/ic-temp-sensor-5v-smd/dp/1469229 € | 0,72
5 | RGB-ledstrips or RGB-SMD-Power-LEDS | To indicate foods | ≈ 7 pieces | http://www.dx.com/p/12v-54-led-rgb-light-strip-50cm-11304#.VNd5I_mG8nM € | 45,00
6 | MOSFET, N, 55V, 110A, TO-220 | To control RGB-LEDS (3/shield) T | 4 | http://be.farnell.com/international-rectifier/irf3205pbf/mosfet-n-55v-110a-to-220/dp/1704017 € | 5,39
7 | IRF3205SPBF MOSFET SMD | For Final (SMD)-purposes | 17 | http://be.farnell.com/international-rectifier/irf3205spbf/mosfet-n-55v-110a-d2-pak/dp/8648069 € | 1,74
8 | Flatcable or Ethernet (board)plugs (4-W) | To connect the BUS-system (2 for each) | 12 | OAMK | /
9 | HC-SR04 (I have one from Belgium) | To detect distance user | 1 | http://www.dx.com/nl/p/hc-sr04-ultrasonic-sensor-distance-measuring-module-133696 € | 3,00
10 | Temprature-sensor | checking (mabe controlling) | 2 | http://www.dx.com/p/arduino-digital-temperature-humidity-sensor-module-121350#.VNd6mPmG8nM € | 5,00
11 | Motion detector | To detect users for energy saving | 1 | http://www.dx.com/p/robox-arduino-ir-body-infrared-sensor-module-white-green-144209#.VOWh7fmG8nM € | 3,00

### Estimated needs:

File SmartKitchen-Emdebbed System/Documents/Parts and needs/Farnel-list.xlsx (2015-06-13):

Supplementary component list:
ID: | Subject/Component: | Use/Part: | Quantity | Shop/Example/Info: | ≈Price pp:
1 | IC, I2C BUS EXPANDER 16DIP | To test on breadboads | 3 | http://be.farnell.com/texas-instruments/pcf8574an/ic-i2c-bus-expander-16dip/dp/1703443 | €1.17
2 | I/O EXPANDER, 8BIT, I2C, TSSOP-20 | For Final (SMD)-purposes | 6 | http://be.farnell.com/texas-instruments/pcf8574apw/i-o-expander-8bit-i2c-tssop-20/dp/2335654 | €1.24
3 | LM335AZ/NOPB IC, TEMP SENSOR, 5V, 3-TO-92 | To measure temp in & outside | 3 | http://be.farnell.com/texas-instruments/lm335az-nopb/ic-temp-sensor-5v-3-to-92/dp/1469227 | €1.20
4 | IC, TEMP SENSOR, 5V, SMD | For Final (SMD)-purposes | 2 | http://be.farnell.com/texas-instruments/lm335m-nopb/ic-temp-sensor-5v-smd/dp/1469229 | €0.72
5 | RGB-ledstrips or RGB-SMD-Power-LEDS | To indicate foods | 7 | http://www.dx.com/p/12v-54-led-rgb-light-strip-50cm-11304#.VNd5I_mG8nM | €45.00
6 | MOSFET, N, 55V, 110A, TO-220 | To control RGB-LEDS (3/shield) T | 4 | http://be.farnell.com/international-rectifier/irf3205pbf/mosfet-n-55v-110a-to-220/dp/1704017 | €5.39
7 | IRF3205SPBF MOSFET SMD | For Final (SMD)-purposes | 17 | http://be.farnell.com/international-rectifier/irf3205spbf/mosfet-n-55v-110a-d2-pak/dp/8648069 | €1.74
8 | Flatcable or Ethernet (board)plugs (4-W) | To connect the BUS-system (2 for each) | 12 | OAMK | €0.00
9 | HC-SR04 (I have one from Belgium) | To detect distance user | 1 | http://www.dx.com/nl/p/hc-sr04-ultrasonic-sensor-distance-measuring-module-133696 | €3.00
10 | Temprature-sensor | checking (mabe controlling) | 2 | http://www.dx.com/p/arduino-digital-temperature-humidity-sensor-module-121350#.VNd6mPmG8nM | €5.00
11 | Motion detector | To detect users for energy saving | 1 | http://www.dx.com/p/robox-arduino-ir-body-infrared-sensor-module-white-green-144209#.VOWh7fmG8nM | €3.00
12 | LM3940 1-A Regulator for 5-V to 3.3-V | Vcc for SC16IS750 | 10 | http://be.farnell.com/texas-instruments/lm335az-nopb/ic-temp-sensor-5v-3-to-92/dp/1469227 | €1.20
13 | Short female-female flatcable 4W | Connecting leds | 8 | http://be.farnell.com/texas-instruments/lm335m-nopb/ic-temp-sensor-5v-smd/dp/1469229 | €5.60
14 | 3 way dipswitches | adressing for leds | 6 | http://nl.farnell.com/omron-electronic-components/a6s3102h/switch-dip-3-way-sealed/dp/1960896 | €3.00
15 | Ledstrip connector | to connect strip to board | 8 | http://fi.farnell.com/phoenix-contact/ptf-0-3-4-wb-1-8-h/plug-in-connector-pcb-4way-w-wires/dp/2365432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 | €0.00
16 | Flatcable 6 wire / meter | To connect devices/modules | 8 | http://fi.farnell.com/pro-power/htc4039-1/cable-flat-7x2-46mm-white-100m/dp/1643747 | €18.00
17 | Capacitors 4µ7 16V | Current peaks | 14 | http://fi.farnell.com/panasonic-electronic-components/eee1ca4r7nr/cap-alu-elec-4-7uf-16v-smd/dp/2326125 | €0.36
18 | PCF8574A | I2C addressing | 10 | http://fi.farnell.com/texas-instruments/pcf8574adwr/i-o-expander-8bit-100khz-soic/dp/2407150 | €1.68
19 | Lower header (7mm instead of 8,5mm) 10-pin | To connect NFC-reader | 12 | OAMK | €0.00
20 | SMD dipswitches | for addressing | 10 | http://fi.farnell.com/omron-electronic-components/a6s3102h/switch-dip-3-way-sealed/dp/1960896 | €1.74
21 | 5mm Red LED | Power indication | 10 | http://fi.farnell.com/kingbright/l-57iid/led-bi-polar-5mm-red/dp/2217953 | €0.26
22 | 5mm Yellow LED | Reader indicaton | 10 | http://fi.farnell.com/kingbright/l-57yyd/led-bi-polar-5mm-yellow/dp/2217955 | €0.26
23 | Sockets 6wire | To connect devices/modules | 5 | http://fi.farnell.com/molex/95009-7661/socket-fcc-68-6way-6contact/dp/2076092 | €0.72
24 | Power connector | To give the system power | 2 | http://fi.farnell.com/lumberg/1613-18/socket-dc-power-12v-1a/dp/1308873 | €1.53
25 | Interference capacitors 100nF | interference over 5V-lines | 14 | http://fi.farnell.com/kemet/c0603c104k8ractu/cap-mlcc-x7r-100nf-10v-0603/dp/2112833 | €0.01
26 | Screen or Tablet | GUI on fridge | 1 | OAMK (Web-application) | €0.00
27 | Arduino Mega | Controlling fridge | 2 | OAMK | €0.00
28 | RGB-ledstrips | To indicate needed foods | 12 | http://www.dx.com/p/12v-54-led-rgb-light-strip-50cm-11304#.VNd5I_mG8nM | €20.00
29 | Compennts custom-Arduino-shield | RGB driver,TIP31, expierence,... | 5 | https://www.dfrobot.com/index.php?route=product/product&product_id=1032 | €0.00
30 | HC-SR04 | To detect distance user | 1 | http://www.dx.com/nl/p/hc-sr04-ultrasonic-sensor-distance-measuring-module-133696 | €3.00
31 | Temprature-sensor | checking (mabe controlling) | 3 | http://www.dx.com/p/arduino-digital-temperature-humidity-sensor-module-121350#.VNd6mPmG8nM | €5.00
32 | NFC-readers | To read products | 5 | OAMK | €80.00
33 | NFC-stickers | To identify ingredients | 100 | http://www.dx.com/p/000142-nfc-tag-smart-electronic-high-frequency-tag-silver-298982#.VNd9svmG8nM | €15.00
 |  | Total: | 314 | Total: | €224.82

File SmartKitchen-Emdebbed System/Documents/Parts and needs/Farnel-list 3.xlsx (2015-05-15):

Estimated needs:
ID: | Subject/Component: | Use/Part: | Quantity +- | Shop/Example/Info: | ≈Price pp:
 | Hardware:
1 | Flatcable 6 wire | To connect devices/modules | 8m | http://fi.farnell.com/pro-power/htc4039-1/cable-flat-7x2-46mm-white-100m/dp/1643747 | X
2 | Capacitors 4µ7 16V | Current peaks | 14 | http://fi.farnell.com/panasonic-electronic-components/eee1ca4r7nr/cap-alu-elec-4-7uf-16v-smd/dp/2326125 | €0.36
3 | PCF8574A | I2C addressing | 10 | http://fi.farnell.com/texas-instruments/pcf8574adwr/i-o-expander-8bit-100khz-soic/dp/2407150 | €1.68
4 | Lower header (7mm instead of 8,5mm) 10-pin | To connect NFC-reader | 12 | ??? | ???
5 | SMD dipswitches | for addressing | 10 | http://fi.farnell.com/omron-electronic-components/a6s3102h/switch-dip-3-way-sealed/dp/1960896 | €1.74
6 | 5mm Red LED | Power indication | 10 | http://fi.farnell.com/kingbright/l-57iid/led-bi-polar-5mm-red/dp/2217953 | €0.26
7 | 5mm Yellow LED | Reader indicaton | 10 | http://fi.farnell.com/kingbright/l-57yyd/led-bi-polar-5mm-yellow/dp/2217955 | €0.26
8 | Sockets 6wire | To connect devices/modules | 5 | http://fi.farnell.com/molex/95009-7661/socket-fcc-68-6way-6contact/dp/2076092 | €0.72
9 | Power connector | To give the system power | 2 | http://fi.farnell.com/lumberg/1613-18/socket-dc-power-12v-1a/dp/1308873 | €1.53
10 | Interference capacitors 100nF | interference over 5V-lines | 14 | http://fi.farnell.com/kemet/c0603c104k8ractu/cap-mlcc-x7r-100nf-10v-0603/dp/2112833 | €0.01

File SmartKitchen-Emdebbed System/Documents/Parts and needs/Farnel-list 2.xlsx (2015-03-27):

Estimated needs:
ID: | Subject/Component: | Use/Part: | Quantity | Shop/Example/Info: | ≈Price pp:
 | Hardware:
1 | Transprant case
2 | LM3940 1-A Regulator for 5-V to 3.3-V | Vcc for SC16IS750 | 10
3 | Short female-female flatcable 4W | Connecting leds | 8
4 | 3 way dipswitches | adressing for leds | 6 | http://nl.farnell.com/omron-electronic-components/a6s3102h/switch-dip-3-way-sealed/dp/1960896
5 | Ledstrip connector | to connect strip to board | 8 | http://fi.farnell.com/phoenix-contact/ptf-0-3-4-wb-1-8-h/plug-in-connector-pcb-4way-w-wires/dp/2365432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
6
7
8
9
10
11

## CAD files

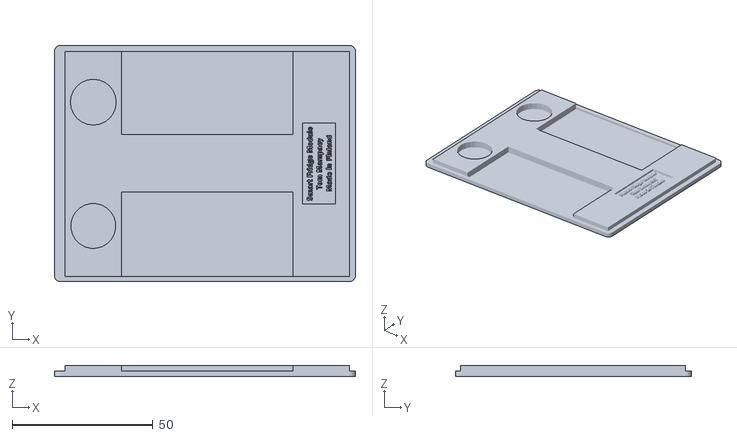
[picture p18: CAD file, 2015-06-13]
SmartKitchen-Emdebbed System/Hardware/3D Design/Lid_SmartFridge.stl
107.0 x 84.0 x 4.00

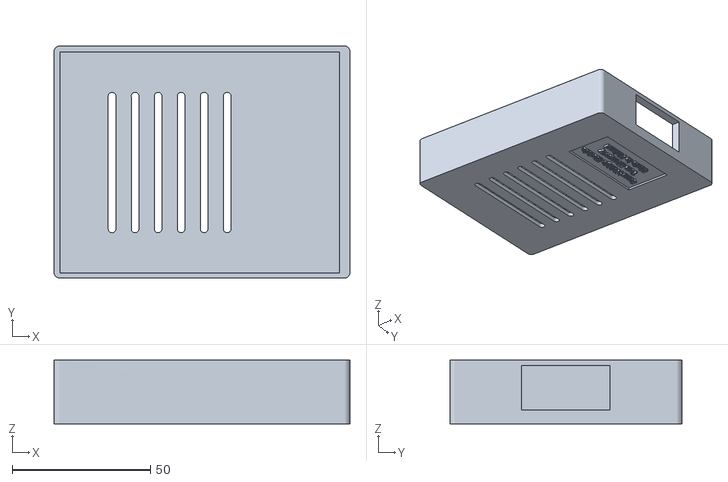
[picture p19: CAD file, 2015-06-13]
SmartKitchen-Emdebbed System/Hardware/3D Design/Box_SmartFridge.stl
107.0 x 84.0 x 23.0

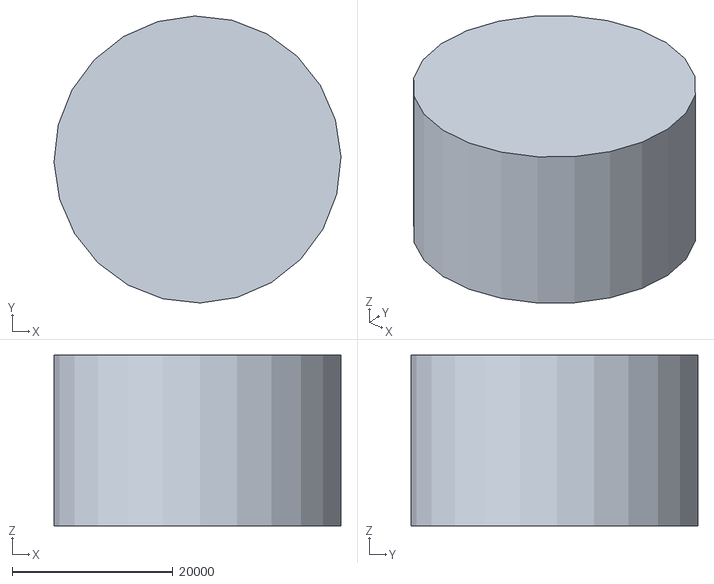
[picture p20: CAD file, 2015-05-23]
SmartKitchen-Emdebbed System/Hardware/3D Design/cilinder.stl
35750.0 x 35750.0 x 21280.0

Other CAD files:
SmartKitchen-Emdebbed System/Hardware/3D Design/Box.skp
SmartKitchen-Emdebbed System/Hardware/3D Design/lid upsidedown.skp
SmartKitchen-Emdebbed System/Hardware/3D Design/lit.skp

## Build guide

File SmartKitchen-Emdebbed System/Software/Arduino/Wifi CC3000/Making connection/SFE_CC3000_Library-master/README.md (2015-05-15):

SFE_CC3000_Library
==============

Arduino library for the TI CC3000 WiFi [Shield](https://www.sparkfun.com/products/12071) and [Breakout Board](https://www.sparkfun.com/products/12072).

Version
-------

**v1.6**

Known Issues
------------

Note that the SFE_CC3000_Library was tested with CC3000 firmware v1.24.

The following are known problems with the library and are being actively worked on:

* Tx/Rx buffers for the CC3000 can easily overflow. Buffer checks need to be added to the library.
* AES encryption for SmartConfig is not supported.
* Static IP is not working at this time (only DHCP works).
* HTTP POST requests work but do not print the whole server response to the console.
* The library does not work with any Teensey boards. Only ATmega328- and ATmega2560-based Arduinos have been tested.
* UDP has been tested for transmit only. Receiving UDP packets on the CC3000 is currently not working.

Getting Started
---------------

* Download the Git repository as a ZIP ("Download ZIP" button)
* Unzip
* Copy the entire directory (SFE_CC3000_Library) to <Arduino installation directory>/libraries
* Open the Arduino program
* Select File -> Examples -> SFE_CC3000_Library -> WebClient
* Change ap_ssid and ap_password to match your WiFi's SSID and password
* If your WiFi's security is anything other than WPA2, change ap_security to one of WLAN_SEC_UNSEC, WLAN_SEC_WEP, WLAN_SEC_WPA, or WLAN_SEC_WPA2
* Plug in your Arduino and CC3000 board
* Go to Tools -> Board and select your Arduino board
* Go to Tools -> Serial Port and select the COM port of your Arduino board
* Click "Upload"
* Go to Tools -> Serial Monitor
* Ensure the baud rate is set at 115200 baud
* The program should connect and print out the HTML of [www.example.com](http://www.example.com)

Version History
---------------

**v1.6**

* Fixed SD card incompatibility issue. Again. (I broke it in v1.4)

**v1.5**

* Added support for ATmega32u4 (Arduino Leonardo)

**v1.4**

* Added CS pin de-assertion on init to allow for other non-default CS pins

**v1.3**

* Merged pull request from Jacob Rosenthal (https://github.com/jacobrosenthal)
  * Changed IP Addresses to conform to Arduino's other networking libraries (e.g. using the IPAddress class)
  * Implemented UDP connections

**v1.2**

* Added support for the Arduino Mega

**v1.1**

* Fixed SD card incompatibility issues
* Added WebClientSD.ino example sketch to show SD card working with CC3000

**v1.0**

* Initial release
* Manual connection implemented
* SmartConfig and FastConnect implemented
* Ping implemented
* TCP connections implemented
* Users can perform HTTP GET and HTTP POST

License
-------

This code is beerware; if you see me (or any other SparkFun employee) at the local, and you've found our code helpful, please buy us a round!

Distributed as-is; no warranty is given.

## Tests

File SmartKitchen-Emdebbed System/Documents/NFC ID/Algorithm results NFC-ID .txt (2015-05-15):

yellow: 11 911831811831191251911251251891871831911912372531 911811811831191251911251251891871831 911912372351911831811831191251911251251891871831911912372351 9118318118311912519112512518
      ID:  911831811831191251911251251891871831911912372351
		11 911831811831 19125191125125189187183191191237235191183181 1831191251911251251891871831911912372351911831811831 19125191125125189187183191191237235191183181183119125191125125189187183191191237235191183181183119125191125
		   911831811 83119125191125125189187183191191237235191183181 1831191251911251251891871831911912372351911831811831 19125191125125189187183191191237235191183181183119125191125125189187183191191237235191183181183119125191125
		
White:  11 911831912551191252352452472191872512511072351911831 911911191251911251251891871831 911912372351911831911911192531 911251211891871831911912372351 9118319119111912519
		11 911831911 911191251911251251891871831911912372351911831911 91119125191125125189187183191191237235191183191191119125191125125189187183191191237235191183191191119125191125125189187183191191237235191183191191119125191125125189187183191191237235191183191191
		
Green:  1191183187123119125191125125189187183191191237235191183187123119125191125125189187183191191237235191183187123119125191125125189187183191191237235191183187123119125191125125189187183191191237235191183187123119125191125125189187183191191237235191183187123119125191125125189187183191191237235191183187123119125191125125189187183191191237235191183187123119125191125125189187183191191237191191188191125191203191191191191191191191191191191189191125191183191191191191191191235191183191191191179191191191191191191191191191191121190191191191191191191237191187191235191183191191191191191191191191247191113191123191191191191191191191

Card: 	

Original received data:
----------------------
1 MPU: 1191183187191123123119189191183191187191191237235191183187191123123119189191183255187191191237235191183187191123123119189191183191187191191237235191183187191123123119189191183191187191191237235191183187191
3 MPU: 1191183187191123119119189191183191187191191237235191183187191123119119189191183191187191191237235191183187191123119119189191183191187191191237235191183187191123119119189191183191187191191
Yel:   1191183181183119125191125125189187183191191237235191183181183119125191125125189187183191191237235191183181183119125191125125189187183191191237235191183181183119125191125125189187183191191237235191183181183119125191125
Whi:   1191183191191119125191125125189187183191191237235191183191191119125191125125189187183191191237235191183191191119125191125125189187183191191237235191183191191119125191125125189187183191191237235191183191191119125191125125189187183191191237235191183191191
Gr:    1191183187123119125191125125189187183191191237235191183187123119125191125125189187183191191237235191183187123119125191125125189187183191191237235191183187123119125191125125189187183191191237235191183187123119125191125125189187183191191237235191183187123119125191125125189187183191191237235191183187123119125191125125189187183191191237235191183187123119125191125125189187183191191237191191188191125191203191191191191191191191191191191189191125191183191191191191191191235191183191191191179191191191191191191191191191191121190191191191191191191237191187191235191183191191191191191191191191247191113191123191191191191191191191		
Card W:1125125119191183117189187237235125125119191183117189187237235125125119191183117189187237235125125119191183125189187237235125125119191183117189187237235125125119191183117189187237235125125119191183117189187
Card A:1187181189117187117183125237235187181189117187117183125237235187181189117187117183125237235187181189245187117183125237235187181189117187117183125237235187181189117187117183125237235187181189117187117183125237235187181189117187
Nokia: 118112318318311719118312523723518112318318311719118312523723518112318318311719118312523723518112318318311719118312523723518112318318311719118312523723518112318318311719118312523723518112321991215187

First algo:
----------------------
1 MPU: 11911831 871911231 23 119189191183191187191191237235191183187191123123119189191183 2551 871911912372351911831871911 23123119189191183191187191191237235191183187191123123119189191183191187191191237235191183187191
2 MPU: 11911831 871911231 23 119189191183191187191191237235191183187191123123119189191183 1911 871911912372351911831871911 7517587251187251219251251107235191183187191123123119189191183191
3 MPU: 11911831 871911231 19 119189191183191187191191237235191183187191123119119189191183 1911 871911912372351911831871911 23119119189191183191187191191237235191183187191123119119189191183191187191191
S/D:   S		D	  S		D S    !   								D     S    X									  D		S    X                                      D     S	   X									 D
Yel:   11911831 81183 11912 5 1911251251891871831911912372351911831 81183 1191251911251251891871831911912372351911831 81183 1191251911251251891871831911912372351911831 81183 119125191125125189187183191191237235191183 181183119125191125
Whi:   11911831 91191 11912 5 1911251251891871831911912372351911831 91191 1191251911251251891871831911912372351911831 91191 1191251911251251891871831911912372351911831 91191 119125191125125189187183191191237235191183 191191119125191125125189187183191191237235191183191191
Gr:    11911831 87123 11912 5 1911251251891871831911912372351911831 87123 1191251911251251891871831911912372351911831 87123 1191251911251251891871831911912372351911831 87123 119125191125125189187183191191237235191183 187123119125191125125189187183191191237235191183187123119125191125125189187183191191237235191183187123119125191125125189187183191191237235191183187123119125191125125189187183191191237191191188191125191203191191191191191191191191191191189191125191183191191191191191191235191183191191191179191191191191191191191191191191121190191191191191191191237191187191235191183191191191191191191191191247191113191123191191191191191191191		
Bl:    11911831 83191 11912 3 1911251251891871831911912372351911831 83191 1191231911251251891871831911912372351911831 83191 1191231911251251891871831911912372351911831 83191 119123191125125189187183191191237235191183
					  ---------------------------------------------       -------------------------------------------       -------------------------------------------       ---------------------------------...												
Card W:1125125119191183117189187237235125125119191183117189187237235125125119191183117189187237235125125119191183125189187237235125125119191183117189187237235125125119191183117189187237235125125119191183117189187
Card A:1187181189117187117183125237235187181189117187117183125237235187181189117187117183125237235187181189245187117183125237235187181189117187117183125237235187181189117187117183125237235187181189117187117183125237235187181189117187
Nokia: 118112318318311719118312523723518112318318311719118312523723518112318318311719118312523723518112318318311719118312523723518112318318311719118312523723518112318318311719118312523723518112321991215187

2nd algo:
----------------------

YL: 48525352706548656557515256481310485253527065486565575152564813104852535270654865655751525648131048525352706548656557515256481310485253527065486565575152564813104852535270654865655751525648131048525352706548656557515256481310485253527065486565575152564813104852535270654865655748484848484
    48525352706548656557515256481310 48525352706548656557515256481310 4852535270654865655751525648131048525352706548656557515256481310485253527065486565575152564813104852535270654865655751525648131048525352706548656557515256481310485253527065486565575152564813104852535270654865654865484848487048
GR: 48525167706548656557515256481310 485251677065486565575152564813104852516770654865655751525648131048525167706548656557515256481310485251677065486565575152564813104852516770654865655751525648131048525167706548656557515256481310485251677065486565575152564813104852516770654865655748
WH: 48525656706548656557515256481310 4852565670654865655751525648131048525656706548656557515256481310485256567065486565575152564813104852565670654865655751525648131048525656706548656557515256481310485256567065486565575152564813104852565670654865655751525648131048525656706548656548486548
BL: 48525448706648656557515256481310 485254487066486565575152564813104852544870664865655751525648131048525448706648656557515256481310485254487066486565575152564813104852544870664865655751525648131048525448706648656557515256481310485254487066486565575152564813104852544870664865654848664848481352
RE: 48525654706548656557515256481310 485256547065486565575152564813104852565470654865655751525648131048525654706548656557515256481310485256547065486565575152564813104852565470654865655751525648131048525654706548656557515256481310485256547065486565575152564813104852565470654865654813564848485148
MC1:48525148666670494852485056481310 485251486666704948524850564813104852514866667049485248505648131048525148666670494852485056481310485251486666704948524850564813104852514866667049485248505648131048525148666670494852485056481310485251486666704948524850564813104852514866667049484848704848
MC2:48525148666770494852485056481310 485251486667704948524850564813104852514866677049485248505648131048525148666770494852485056481310485251486667704948524850564813104852514866677049485248505648131048525148666770494852485056481310485251486667704948524850564813104852514866677049484848484848486648
MC3:48525148677070494852485056481310 4852514867707049485248505648131048525148677070494852485056481310485251486770704948524850564813104852514867707049485248505648131048525148677070494852485056481310485251486770704948524850564813104852514867707049485248505648131048525148677070494852484848484848
Cwh:4852695751131065657048526957511310656570 4852695751131065657048526957511310656570 4852695751131065657048526957511310656570485269575113106565704852695751131065657048526957511310

NOK:53675455695655651310536754556956556513105367545569565565131053675455695655651310536754556956556513105367545569565565131053675455695655651310536754556956556513105367545569565565131053675455695655651310536754556956556513105367545569565565131053675455695655651310
CAL:5153576951695265131051535769516952651310515357695169526513105153576951695265131051535769516952651310515357695169526513105153576951695265131051535769516952651310515357695169526513105153576951695265131051535769516952651310

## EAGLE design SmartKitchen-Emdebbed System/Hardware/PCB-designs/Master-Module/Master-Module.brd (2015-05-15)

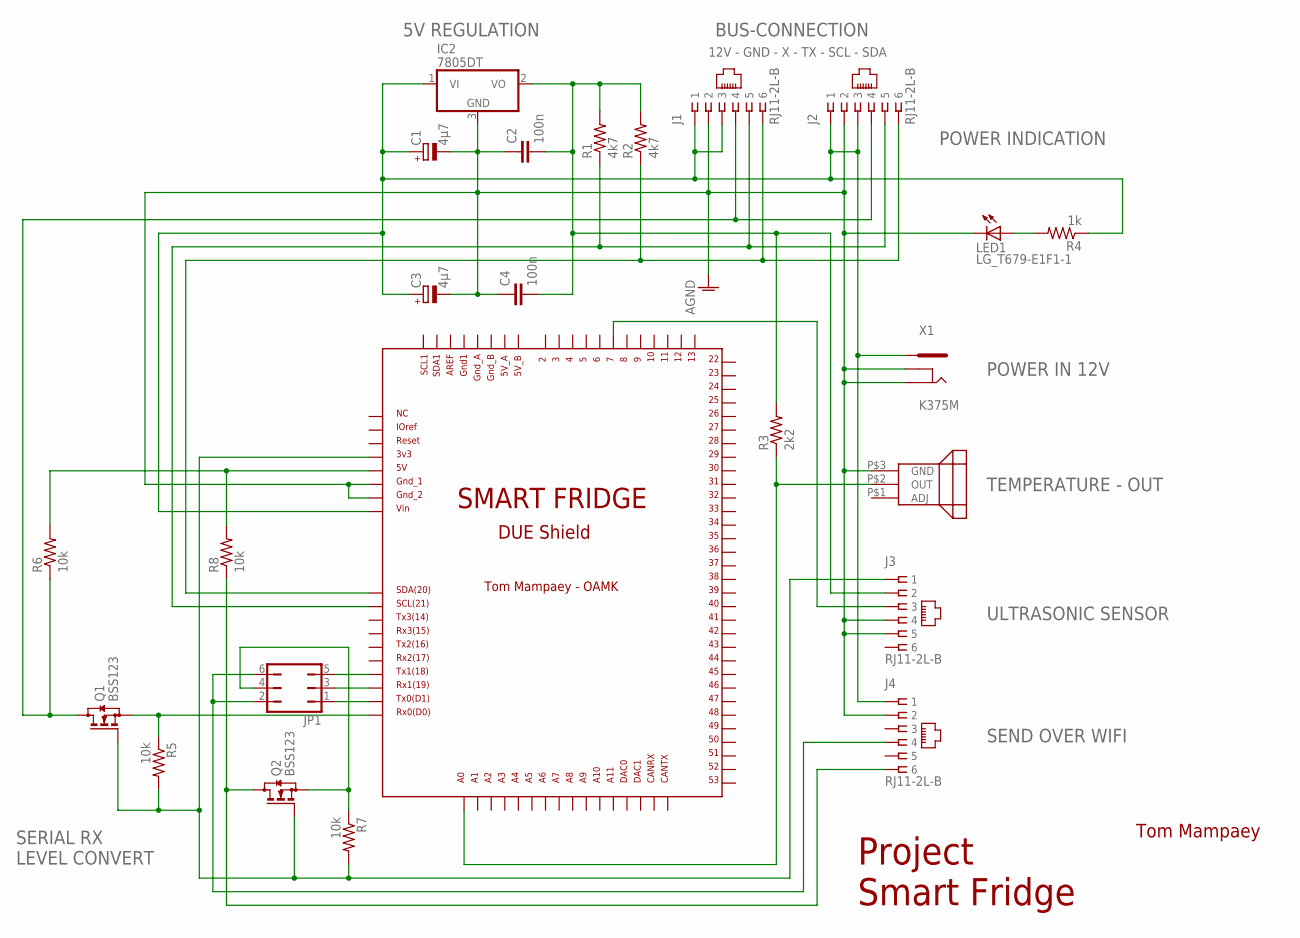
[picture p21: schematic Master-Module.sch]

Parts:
C1, C3: 4µ7; PANASONIC_B
C2, C4: 100n; C0603
IC2: 7805DT; TO252
J1, J2, J3: RJ11-2L-B; RJ11-NO_SHIELD
J4: RJ11-2L-B; RJ11-NO_SHIELD; MPN RJ11-2L-B
JP1: JP3Q
LED1: LG_T679-E1F1-1; PLCC2
Q1, Q2: BSS123; SOT23
R1, R2: 4k7; R0402
R3: 2k2; R0402
R4: 1k; R0402
R5, R6, R7, R8: 10k; R0402
U$1: DUE(NORMAL)
U$2: LM335
X1: K375M

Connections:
AGND: C1.-, C2.1, C3.-, C4.1, IC2.3 (GND), J1.2, J2.2, J3.4, J3.5, J4.2, LED1.C, U$1.GND_1, U$1.GND_2, U$2.P$3 (GND), X1.P$1 (2), X1.P$6 (3)
unnamed: J1.6, J2.6, R2.1, U$1.SDA
unnamed: J1.4, J2.4, Q1.3 (D), R6.1
unnamed: J1.5, J2.5, R1.1, U$1.SCL
unnamed: R6.2, R8.2, U$1.5V
unnamed: R3.1, U$1.A0, U$2.P$2 (OUT)
unnamed: J3.3, U$1.7
unnamed: LED1.A, R4.2
unnamed: C2.2, C4.2, IC2.2 (VO), J3.2, R1.2, R2.2, R3.2
unnamed: Q1.2 (S), R5.1, U$1.RX0
unnamed: JP1.1, U$1.TX0
unnamed: J3.1, Q1.1 (G), Q2.1 (G), R5.2, R7.2, U$1.3V3
unnamed: JP1.3, U$1.RX1
unnamed: JP1.5, U$1.TX1
unnamed: J4.4, JP1.2, JP1.6
unnamed: J4.6, Q2.3 (D), R8.1
unnamed: JP1.4, Q2.2 (S), R7.1
unnamed: C1.+, C3.+, IC2.1 (VI), J1.1, J1.3, J2.1, J2.3, J4.1, R4.1, U$1.VIN, X1.P$7 (1)

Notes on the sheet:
12V - GND - X - TX - SCL - SDA
BUS-CONNECTION
5V REGULATION
POWER IN 12V
ULTRASONIC SENSOR
TEMPERATURE - OUT
Tom Mampaey
Project Smart Fridge
POWER INDICATION
SERIAL RX LEVEL CONVERT
SEND OVER WIFI

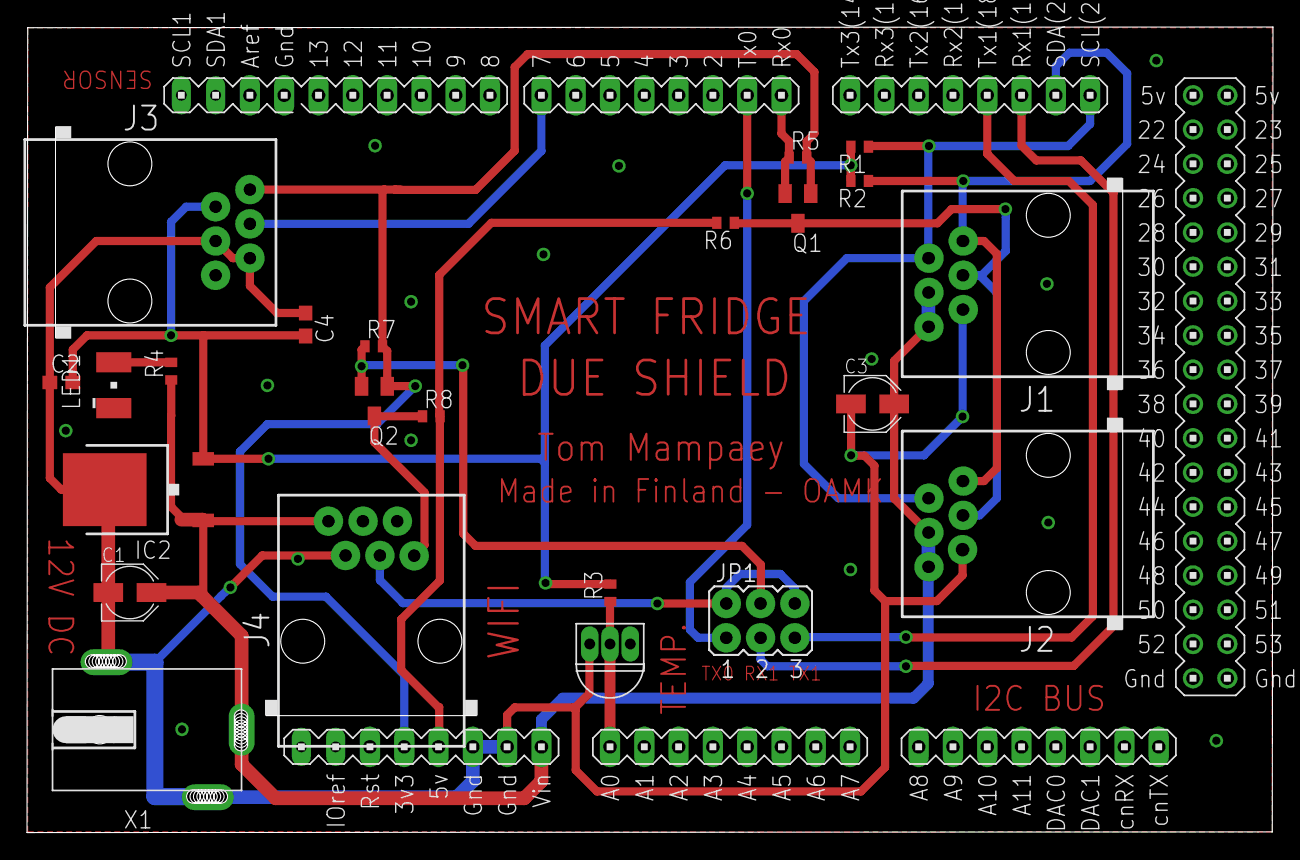
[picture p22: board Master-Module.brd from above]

Board: 2 copper layers, 92.3 x 59.7 mm, 24 parts (0 on the bottom side), 18 nets.

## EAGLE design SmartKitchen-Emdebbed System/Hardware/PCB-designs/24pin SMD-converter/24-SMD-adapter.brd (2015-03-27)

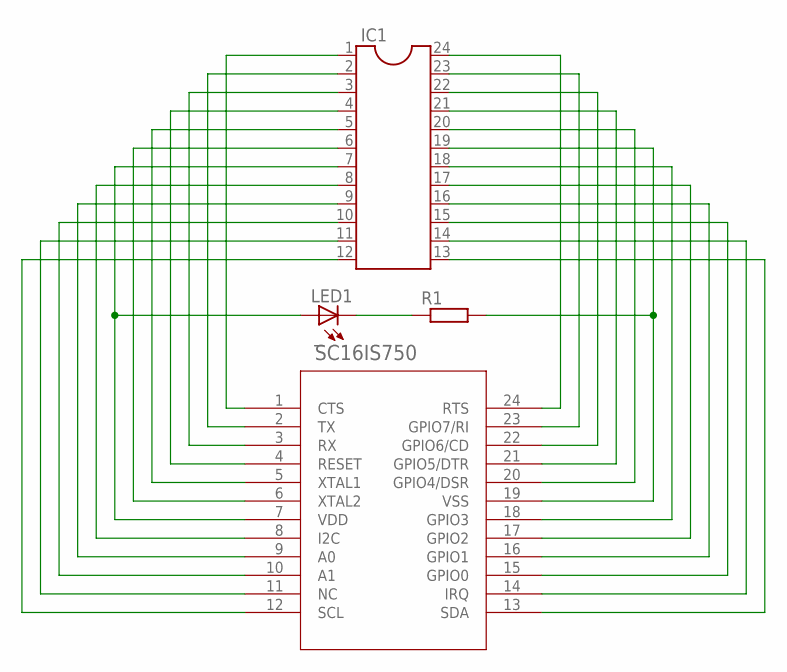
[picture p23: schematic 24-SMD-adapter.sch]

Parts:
IC1: DIL24-6
LED1: LEDSML1206; SML1206
R1: R-EU_R0402; R0402
_: SC16IS750; SOT361_1_M

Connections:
unnamed: IC1.1, _.1 (CTS)
unnamed: IC1.2, _.2 (TX)
unnamed: IC1.3, _.3 (RX)
unnamed: IC1.4, _.4 (RESET)
unnamed: IC1.5, _.5 (XTAL1)
unnamed: IC1.6, _.6 (XTAL2)
unnamed: IC1.7, LED1.A, _.7 (VDD)
unnamed: IC1.8, _.8 (I2C)
unnamed: IC1.9, _.9 (A0)
unnamed: IC1.10, _.10 (A1)
unnamed: IC1.11, _.11 (NC)
unnamed: IC1.12, _.12 (SCL)
unnamed: IC1.24, _.24 (RTS)
unnamed: IC1.23, _.23 (GPIO7/RI)
unnamed: IC1.22, _.22 (GPIO6/CD)
unnamed: IC1.21, _.21 (GPIO5/DTR)
unnamed: IC1.20, _.20 (GPIO4/DSR)
unnamed: IC1.19, R1.2, _.19 (VSS)
unnamed: IC1.18, _.18 (GPIO3)
unnamed: IC1.17, _.17 (GPIO2)
unnamed: IC1.16, _.16 (GPIO1)
unnamed: IC1.15, _.15 (GPIO0)
unnamed: IC1.14, _.14 (IRQ)
unnamed: IC1.13, _.13 (SDA)
unnamed: LED1.C, R1.1

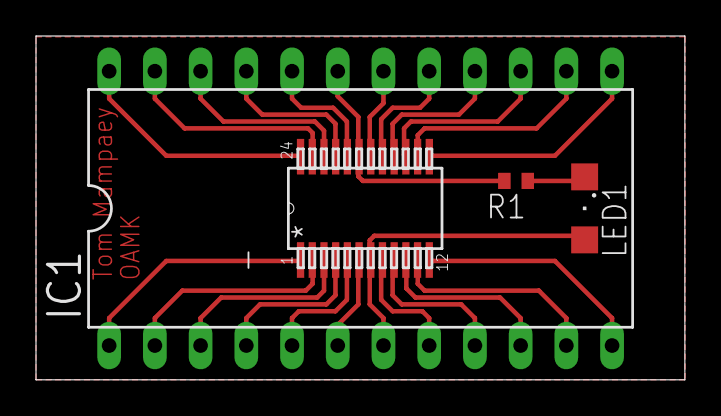
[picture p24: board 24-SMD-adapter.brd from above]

Board: 2 copper layers, 36.0 x 19.1 mm, 4 parts (0 on the bottom side), 25 nets.

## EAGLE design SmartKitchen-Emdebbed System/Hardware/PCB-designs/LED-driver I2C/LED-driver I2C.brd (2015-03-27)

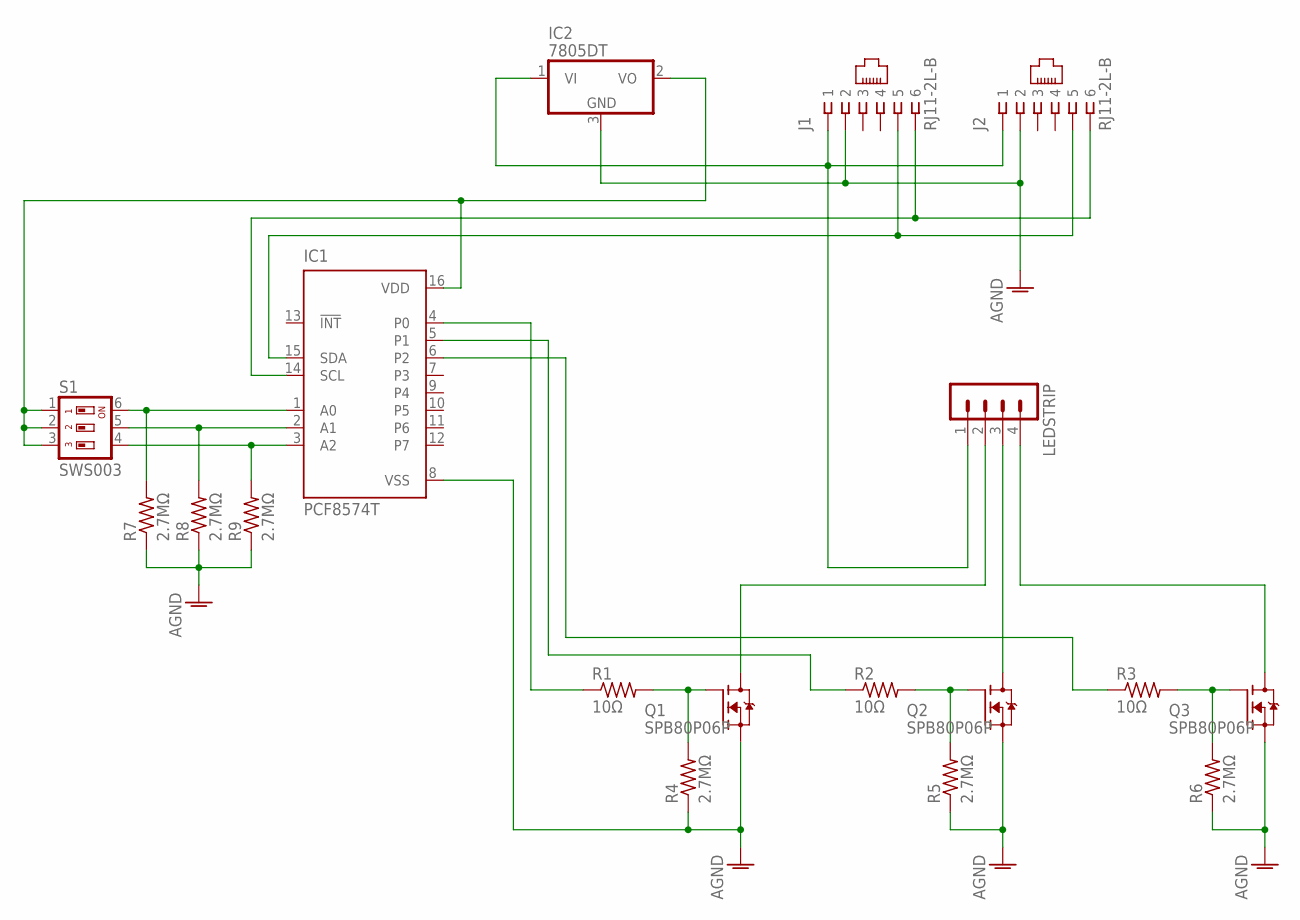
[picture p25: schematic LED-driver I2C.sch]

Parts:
IC1: PCF8574T; SO16W
IC2: 7805DT; TO252
J1, J2: RJ11-2L-B; RJ11-NO_SHIELD
LEDSTRIP: MA04-1
Q1, Q2, Q3: SPB80P06P; TO263
R1, R2, R3: 10Ω; R0402
R4, R5, R6, R7, R8, R9: 2.7MΩ; R0402
S1: SWS003; SMS-003

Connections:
AGND: IC1.8 (VSS), IC2.3 (GND), J1.2, J2.2, Q1.2 (D), Q2.2 (D), Q3.2 (D), R4.1, R5.1, R6.1, R7.1, R8.1, R9.1
unnamed: IC1.15 (SDA), J1.5, J2.5
unnamed: IC1.14 (SCL), J1.6, J2.6
unnamed: Q1.1 (G), R1.2, R4.2
unnamed: Q2.1 (G), R2.2, R5.2
unnamed: Q3.1 (G), R3.2, R6.2
unnamed: LEDSTRIP.2, Q1.3 (S)
unnamed: LEDSTRIP.3, Q2.3 (S)
unnamed: LEDSTRIP.4, Q3.3 (S)
unnamed: IC2.1 (VI), J1.1, J2.1, LEDSTRIP.1
unnamed: IC1.1 (A0), R7.2, S1.6
unnamed: IC1.2 (A1), R8.2, S1.5
unnamed: IC1.3 (A2), R9.2, S1.4
unnamed: IC1.16 (VDD), IC2.2 (VO), S1.1, S1.2, S1.3
unnamed: IC1.4 (P0), R1.1
unnamed: IC1.5 (P1), R2.1
unnamed: IC1.6 (P2), R3.1

Board: 2 copper layers, 18 parts (0 on the bottom side), 17 nets, no tracks yet.

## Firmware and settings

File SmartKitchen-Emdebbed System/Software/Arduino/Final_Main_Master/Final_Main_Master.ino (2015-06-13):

/* 

Master Module of Smart Fridge
-----------------------------
Made by Tom Mampaey
at 'OAMK University of Applied sciences'
May 2015

The mastermodule controls all the connected slavemodules by I2C-protocol on the two RJ-11 connectors (on right).
It also has a motionsensor port (on left), a temraturesensor and a output port to Wifi (underneath).
The mastermodule is powerd by an 12V 1,5A DC adapter

This code controls all the serial switches on the NFC-readers and converts this data to ID's.
Seven diffrent colors can be dedicated to the RGB-strips of the selected Slave Module.
The converted data will be set in a header before sending over the serial line of the output-port.
*/

// Module adresses:
#define  MOD1  56
#define  MOD2  57
#define  MOD3  58
#define  MOD4  59
#define  MOD5  60
#define  MOD1_R  61
#define  MOD2_R  62
#define  MOD3_R  63
#define  MOD4_R  64
#define  MOD5_R  65

// Colors:
#define Off B00000000
#define Read B00000001
#define Green B00000001
#define Red B00000010
#define Yellow B00000011
#define Blue B00000100
#define BrightBlue B00000101
#define Purple B11111110
#define White B11111111

#include <Wire.h>

// NFC
int incomingByte = 0;         // for incoming serial data
char charBuf[100];
char tempcharBuf[100];
String incomingString = "";
String tempString = "";
boolean ReadNFC = true;
int count = 100;
String productID = "0000";
int ReadDelay = 1000;

int Temprature = 20;        // test value
boolean Available = true;

// UserDetection
int duration;                // Stores duration of pulse in
int distance;                // Stores distance
int sensorpin = 7;
int UserDistance = 30;       // in cm

void setup()
{
  Wire.begin();
  Serial.begin(9600);
  ModuleWrite(Off, MOD1);
  ModuleWrite(Off, MOD2);
  ModuleWrite(Off, MOD3);
  ModuleWrite(Off, MOD4);
  ModuleWrite(Off, MOD5);

  ModuleWrite(Off, MOD1_R);
  ModuleWrite(Off, MOD2_R);
  ModuleWrite(Off, MOD3_R);
  ModuleWrite(Off, MOD4_R);
  ModuleWrite(Off, MOD5_R);
}

void loop()
{
  //VisualRGBCheck();          // Visual knight rider of 7 colors for visual check of connection
  // if (DetectUser()) {}      // Can be interactive, from chaning colors to sending to server (works)
  
  for (int i = MOD1_R ; i <= MOD3_R ; i++)  // Read all the readers. 
  {
    SetMod(i);                            // Select NFC-reader
    readID();
    if (productID != "0000")
    {
      ModuleWrite(Green, i - 5);          // Product detected
      Available = true;
    }
    else
    {
      ModuleWrite(Red, i - 5);            // No product
      Available = false;
    }
    SendToWifi(productID, i, Available, Temprature);

    productID = "0000";
    delay(ReadDelay);
  }
}

// Sends assigned data (color or state of serial switch) to specific Module.
void ModuleWrite(byte txData, int Module_Address)
{
  Wire.beginTransmission(Module_Address);
  Wire.write(txData);
  Wire.endTransmission();
}

// Reads the data and translates it to an ID
void readID()
{
  // ----- NFC-Tag Detection -----
  int LengthCharArr = sizeof(charBuf);
  
  for (int i = 0; i <= LengthCharArr; i++)            // Put incomingbytes in a string of 100 chars
  {
    if (Serial.available() > 0) {
      incomingByte = Serial.read();
      tempString = String(incomingByte);
      incomingString += tempString;
    }
  }
  
  incomingString.toCharArray(tempcharBuf, LengthCharArr);  // Put incomingString (size 100) in char array (100)
  incomingString = "";

  boolean StartShifting = false;
  int index = 0;
  for (int i = 0; i <= LengthCharArr; i++)
  {
    if (tempcharBuf[i] == '4' && tempcharBuf[i + 1] == '8' && tempcharBuf[i + 2] == '5' && tempcharBuf[i + 3] == '2' && (i + 3) < LengthCharArr) // Shifting array to brand
    {
      StartShifting = true;
    }
    if (StartShifting)
    {
      charBuf[index] = tempcharBuf[i];
      index++;
    }
  }
  
  for (int i = 6; i <= LengthCharArr; i++)     // Devide the char array in 'boxes' (Starting with 6 because ID never is shorter)
  {
    String boxA = "";
    String boxB = "";

    // Box A
    for (int j = 0; j < i; j++)       // Make the first box bigger every round by adding the first chars starting from char 0 -> 6
    {
      boxA += charBuf[j];             // Add the char at location J (Start: 0 -> 6 and increments each round)
    }

    // Box B
    for (int j = 0; j < i; j++)      // Make the second box bigger every round by adding the chars starting from char 6 -> 12
    {
      if (j + i < LengthCharArr)             // As long as the locations are smaller than the buffersize
      {
        boxB += charBuf[j + i];      // Add the char at the location i + j (starting after chars from box A) 6 -> 12
      }
    }

    // Comparing the boxes
    if (boxA == boxB && boxA != "")
    {
      productID = boxA;    // Final productID
      for ( int i = 0; i < LengthCharArr;  ++i )    // Clear buffer of chars
      {
        charBuf[i] = (char)0;
        tempcharBuf[i] = (char)0;
      }
    }
  }
}
// Puts the variables in headers on the serial line to send out the output port 
void SendToWifi(String iD, int location, boolean Available, int temprature)
{
  char charArray[50];
  String tempStr = "XD" + iD + "DA" + (String)location + "AB" + (String)Available + "BT" + (String)temprature + "TX";

  tempStr.toCharArray(charArray, 50);
  Serial.write(charArray);
}

// Visual knight rider of 7 colors for visual check of connection
void VisualRGBCheck()
{
  int timer = 200;
  for (int count = 0; count < 3; count++) {
    ModuleWrite(Green, MOD1 + count);
    delay(timer);
    ModuleWrite(Red, MOD1 + count);
    delay(timer);
    ModuleWrite(Yellow, MOD1 + count);
    delay(timer);
    ModuleWrite(Blue, MOD1 + count);
    delay(timer);
    ModuleWrite(BrightBlue, MOD1 + count);
    delay(timer);
    ModuleWrite(Purple, MOD1 + count);
    delay(timer);
    ModuleWrite(Green, MOD1 + count);
    delay(timer);
  }
  for (int i = 0; i < 3; i++) {
    for (int count = 0; count < 3; count++) {
      ModuleWrite(Off, 56 + count);
    }
    delay(timer);
    for (int count = 0; count < 3; count++) {
      ModuleWrite(White, 56 + count);
    }
    delay(timer);
  }
}

// Detects users in front of fridge, gives countless options to implement
boolean DetectUser()
{
  pinMode(sensorpin, OUTPUT);
  digitalWrite(sensorpin, LOW);                          // Make pin low before sending a short high to trigger ranging
  delayMicroseconds(2);
  digitalWrite(sensorpin, HIGH);                         // Sends short 10 microsecond high on pin to start ranging
  delayMicroseconds(10);
  digitalWrite(sensorpin, LOW);                          // Set pin low again before waiting for pulse back in
  pinMode(sensorpin, INPUT);
  duration = pulseIn(sensorpin, HIGH);                   // Reads echo pulse in from SRF05 in microseconds
  distance = duration / 58;                              // /58 is distance in cm
  Serial.print("Seesam says: ");
  if ( distance < UserDistance)
  {
    Serial.println("USER DETECTED IN FRONT OF FRIDGE!");
    return true;
  }
  else
  {
    Serial.print("Motion detected on ");                                              // Wait before looping to do it again
    Serial.println(distance);
    return false;
  }
  delay(500);
}

// Configures the modules correctly to make sure only that module is reading!
void SetMod(int SelectedMod)
{
  switch (SelectedMod) {
    case 61:
      ModuleWrite(Purple, MOD1);
      ModuleWrite(White, MOD2);
      ModuleWrite(White, MOD3);
      ModuleWrite(Off, MOD1_R);
      ModuleWrite(Read, MOD2_R);
      ModuleWrite(Off, MOD3_R);
      break;
    case MOD2_R:
      ModuleWrite(White, MOD1);
      ModuleWrite(Purple, MOD2);
      ModuleWrite(White, MOD3);
      ModuleWrite(Off, MOD1_R);
      ModuleWrite(Off, MOD2_R);
      ModuleWrite(Read, MOD3_R);
      break;

    case MOD3_R:
      ModuleWrite(White, MOD1);
      ModuleWrite(White, MOD2);
      ModuleWrite(Purple, MOD3);
      ModuleWrite(Read, MOD1_R);
      ModuleWrite(Off, MOD2_R);
      ModuleWrite(Off, MOD3_R);
      break;
  }
}

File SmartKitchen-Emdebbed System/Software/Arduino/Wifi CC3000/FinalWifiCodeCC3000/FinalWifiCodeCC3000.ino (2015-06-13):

/*
SEND PRODUCT INFORMATION TO SERVER
----------------------------------
Made by Tom Mampaey
at 'OAMK University of Applied sciences'
Finland - May 2015

Gets product information from MASTER-board SmartFridge on Serial 1 line. 
Sends JSON data (PUT) to the server using WiFi

Code based on the GET-request example of WebClient SFE
*/

#include <SPI.h>
#include <SFE_CC3000.h>
#include <SFE_CC3000_Client.h>

// Pins 
#define CC3000_INT 2   // Needs to be an interrupt pin 
#define CC3000_EN  7   // Digital pin
#define CC3000_CS  10  // cs pin (best 10 on if you use uno)

// Connection info data lengths
#define IP_ADDR_LEN 4   // Length of IP address in bytes

// Internet settings (constants)
char ap_ssid[] = "SmartKitchen";          // SSID of network
char ap_password[] = "12345678";          // Password of network
unsigned int ap_security = WLAN_SEC_WPA2; // Security of network
unsigned int timeout = 30000;             // Milliseconds
char server[] = "api.verhofstadt.eu";     // Remote host site
String data = " ";
int led = 50;

// Reading from Master Module
char incommingByte;
String incommingString;
char charArray[80];
boolean initComplete = false;
boolean dataReceived = false;
String NFC_ID = "";
String Address = "";
String Availability = "";
String Temprature = "";

// Global Variables
SFE_CC3000 wifi = SFE_CC3000(CC3000_INT, CC3000_EN, CC3000_CS);
SFE_CC3000_Client client = SFE_CC3000_Client(wifi);

void setup() {
  Serial.begin(9600);
  Serial1.begin(9600);
  pinMode(led, OUTPUT); 
  digitalWrite(led, LOW);

  ConnectionInfo connection_info;
  int i;
  // Initialize Serial port
  Serial.println("----------------------------------");
  Serial.println("SmartFridge CC3000 - PUT to Server");
  Serial.println("----------------------------------");

  // Initialize CC3000 (configure SPI communications)
  if ( wifi.init() ) {
    Serial.println("CC3000 initialization complete");
  } else {
    Serial.println("Error: CC3000 initialization incomplete");
  }

  // Connect using DHCP
  Serial.print("Connecting to SSID: ");
  Serial.println(ap_ssid);
  if (!wifi.connect(ap_ssid, ap_security, ap_password, timeout)) {
    Serial.println("Error: Could not connect to AP");
  }

  // Connection details and print IP address
  if ( !wifi.getConnectionInfo(connection_info) ) {
    Serial.println("Error: Could not obtain connection details");
  } else {
    Serial.print("IP Address: ");
    for (i = 0; i < IP_ADDR_LEN; i++) {
      Serial.print(connection_info.ip_address[i]);
      if ( i < IP_ADDR_LEN - 1 ) {
        Serial.print(".");
      }
    }
    Serial.println();
  }

  // Make TCP connection to remote host
  Serial.print("Performing HTTP PUT to: ");
  Serial.println(server);

  client.connect(server, 80);
  if (client.connected()) { //initiate connection
    Serial.print("Connected to: ");
    digitalWrite(led, HIGH);
  }
  else {
    Serial.print("Failed to connect with: ");
    digitalWrite(led, LOW);
  }
  Serial.println(server);

  /*
    // Make a HTTP GET request (works!)
    client.println("GET /service/exercises HTTP/1.1");
    client.print("Host: ");
    client.println(server);
    client.println("Connection: close");
    client.println();
    Serial.println(); 
  */
}
String inData = "";

void loop()
{
  inData = "";

  if (Serial1.available())
  {
    delay(100);                       //allows all serial sent to be received together
    while (Serial1.available())
    {
      char recieved = Serial1.read();
      inData += recieved;
    }
  }

  if (!inData.equals(""))
  {
    inData.toCharArray(charArray, 100);

    //Constructing Json to PUT
    String ID = GetId();
    String Address = GetAddress();
    String Available = GetAvailability();
    String temprature = GetTemprature();
    data = "{\"IdNFC\":\"" + ID  + "\",\"Address\":\"" + Address + "\",\"Available\":\"" + Available + "\",\"TemperatureFridge\":\"" + temprature + "\"}";
    SendToServer(data);
  }
}

String GetContentByFilterOn(char filter)
{
  bool readd = false;
  bool stopread = false;
  String content = "";

  for (int i = 0; i < sizeof(charArray); i++)
  {
    if (stopread)
    {
      return content;
    }

    if (readd)
    {
      if (charArray[i] != filter)
      {
        content.concat(charArray[i]);
      }
    }

    if (charArray[i] == filter)
    {
      readd = !readd;
      if (readd == false)
      {
        stopread = true;
      }
    }
  }
}

void SendToServer(String data)
{
  if (client.connect(server, 80))
  {
    if (client.connected())
    {
      client.println("PUT /service/Hardware/Product HTTP/1.1");
      delay(5);                                  // added short dealys to avoid overload
      client.print("Host: ");
      client.println(server);
      delay(5);
      client.print("Content-Length: ");
      client.println(data.length());             // without quotes
      delay(5);
      client.println("Cache-Control: no-cache");
      delay(5);
      //client.println("Connection: keep-alive");
      //client.println("Content-Type: text/plain; charset=utf-8");
      //client.println("Content-Transfer-Encoding: base64");
      //client.println("Accept-Encoding: gzip, deflate, sdch");
      client.println("Content-Type: application/json");
      delay(5);
      client.println();
      delay(5);
      client.println(data);
      Serial.println(data);
            for (int i = 0; i < 50; i++){
          char c = client.read();
          Serial.print(c);
      }
      client.stop();
    }
  }
  else
  {
    Serial.println("Time-out: Could not make TCP connection");
    client.connect(server, 80);
  }
}

String GetHeader()
{
  return GetContentByFilterOn('X');    // Filer NFC-ID by data between 'D'
}
String GetId()
{
  return GetContentByFilterOn('D');    // Filer NFC-ID by data between 'D'
}
String GetAddress()
{
  return GetContentByFilterOn('A');    // Filer Address by data between 'A'
}
String GetAvailability()
{
  return GetContentByFilterOn('B');    // Filer Availability by data between 'B'
}
String GetTemprature()
{
  return GetContentByFilterOn('T');    // Filer Temprature by data between 'T'
}

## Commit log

2015-01-21 Finished Concept Report and added Gantt-chart
    [Gantt-chart.xlsx]
2015-02-09 Added Estimated needs
    [Estimated_needs.xlsx]
2015-02-24 A lot of testing and research
    NFC, I2C, SMD, Serial,...
    [Farnel-list.xlsx]
2015-02-26 Working code: Serial I2C interface between twe IC's
    [Farnel-list 2.xlsx]
2015-02-27 PCB: (First) SMD-design adapter/converter
    [24-SMD-adapter.brd, 24-SMD-adapter.sch]
2015-03-10 Components, I2C and testcode
    [Farnel-list 2.xlsx, LED-driver I2C.brd, LED-driver I2C.sch]
2015-03-11 Weather Service added
    Powered by Forecast.io
2015-03-12 Added I2C_scanner to check addresses and operation
2015-03-18 testing the NFC with the ledstrips
2015-03-24 Coding and PCB-design
    [Slave_NFC.brd, Slave_NFC.sch]
2015-03-25 Crazy PCB-designings
    [Slave_NFC.sch]
2015-04-15 .brd files for SMD-desgin
    [Slave_NFC.brd]
2015-04-15 Renamed Embedded system
    [24-SMD-adapter.brd, 24-SMD-adapter.sch, Estimated_needs.xlsx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]
2015-04-15 Testsoftware + Fix problem wire
    [Slave_NFC.brd]
2015-04-16 fixes frontpage button responsive style
2015-04-17 Testing software I2C on PCB's
2015-04-20 Working LEDDRIVER over I2C
2015-04-20 Optimized PCB-board 2.0 with header for MAX232
    [Slave_NFC.brd, Slave_NFC.sch]
2015-04-21 Adding interference capacitors and testingcode
    [Slave_NFC.brd, Slave_NFC.sch]
2015-04-21 fixing powerpeaks and nfc-read
    [Slave_NFC.sch]
2015-04-21 Final PCB-design for NFC-reader modules
    I'm proud
    [Slave_NFC.brd, Slave_NFC.sch]
2015-04-21 Adding farnell-list
    [Farnel-list 3.xlsx]
2015-04-21 adding pull-ups and inh-capacitors to list
    [Slave_NFC.brd, Slave_NFC.sch]
2015-04-24 Custom shield DUE - Master module
    [Master-Module.brd, Master-Module.sch]
2015-04-24 customizing components
    [Master-Module.brd, Master-Module.sch, dc.brd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]
2015-04-24 PCB shield
    [Master-Module.brd, Master-Module.sch]
2015-04-27 Adding stupid level-converter for serial connection
    [Master-Module.brd]
2015-04-27 Finnishing DUE shield
    [Master-Module.brd, Master-Module.sch]
2015-04-27 Fine tunning
    [Master-Module.brd]
2015-04-27 Adding planes and references
    [Master-Module.brd, Master-Module.sch, Slave_NFC.sch]
2015-04-29 Testcommit after sync-error git
    [Add_Five_Rx.ino, Add_Five_Tx.ino, SoftSerialtest.ino]
2015-05-02 Complete redesing Master for Wifi-port
    [Master-Module.brd, Master-Module.sch]
2015-05-02 Adding via's
    [Master-Module.brd]
2015-05-02 Final Master PCB-design
2015-05-10 Cleaning folders
    [Estimated_needs.xlsx, Farnel-list 2.xlsx, Farnel-list 3.xlsx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]
2015-05-10 Adding schematic and distribution to report
    all my work
2015-05-10 CV and MAIN-SCHEMATIC added in report
    [WhatIlearned.xlsx]
2015-05-11 Redesigned wrong component
    [Master-Module.brd, Master-Module.sch]
2015-05-11 Disco-coding finnaly working I2C colorcontrol
2015-05-11 Adding ack to report!
    [WhatIlearned.xlsx]
2015-05-12 Switch to open serial data modules
2015-05-13 Working Wifitest - connect and read html
    [WhatIlearned.xlsx]
2015-05-14 Fixing probels with PUT
    [TestingPUTtoServer.ino, WifiPUTtesHomet.ino]
2015-05-14 Before testing filtermethods
2015-05-14 Filtering method on char and detect reliable tags
2015-05-15 Added filter for Data in fridge + autoreload
    The whole frame is reloading, has to be fixed in the future
2015-05-16 Loading button for myprofile + cleanup
2015-05-18 Dashboard button added
2015-05-18 Dynamic temp and log out button added
2015-05-23 Added 3D-design test (3D-print)
    [cilinder.stl]
2015-06-05 Final 3D-design! ready for printing massproduction
    [Box.skp, Box_SmartFridge.stl, Lid_SmartFridge.stl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]
2015-06-07 Index report and cleaning slave
    [Slave_NFC.sch]
2015-06-10 Adding 'Slave module'-information to report
    [Farnel-list.xlsx, WhatIlearned.xlsx]
2015-06-10 Adding extra comment and Master code to report
    [Farnel-list.xlsx]
2015-06-12 Backup report and PCB information
